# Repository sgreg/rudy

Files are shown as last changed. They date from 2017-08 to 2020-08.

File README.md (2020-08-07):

# RUDY - the Random USB Device

RUDY started out as a test and play-around device for USB development using the [Objective Development V-USB library](https://www.obdev.at/products/vusb/index.html), but also serves as standard ATmega328 development board.

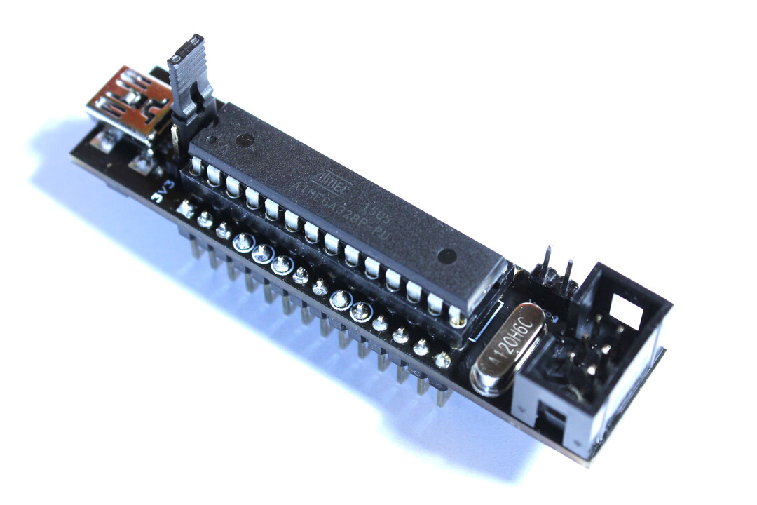
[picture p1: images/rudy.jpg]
RUDY


## Links
- [Official Website](https://rudy.craplab.fi/)
- [Hackaday.io Project Page](https://hackaday.io/project/174101-rudy)

## Features

- breadboard-friendly prototyping board, taking up only one additional row on each side compared to a standalone ATmega328 microcontroller
- Arduino compatible [..ish](firmware/arduino/)
- USB port wired to the ATmega328 for out-of-the-box USB functionality via the V-USB library
- own, dedicated [USB VID/PID pair](http://pid.codes/1209/B00B/) thanks to [pid.codes](http://pid.codes/)
- USB-powered with additional 3.3V voltage regulator on board to select either 5.0 or 3.3V supply voltage
- clocked by 12.0 MHz crystal to comply with V-USB and also 3.3V supply voltage
- 6-pin ISP header for programming, with additional option to power the board directly from the programmer
- power-indicating LEDs mounted under the IC, shining in a mysterious glow (oh yeah)
- DIP28 ATmega328, allowing easy replacement if it ever gets fried (no no)
- fully open source and [certified as such](https://certification.oshwa.org/fi000002.html) by the [Open Source Hardware Association (OSHWA)](https://www.oshwa.org/)

<p align="center">
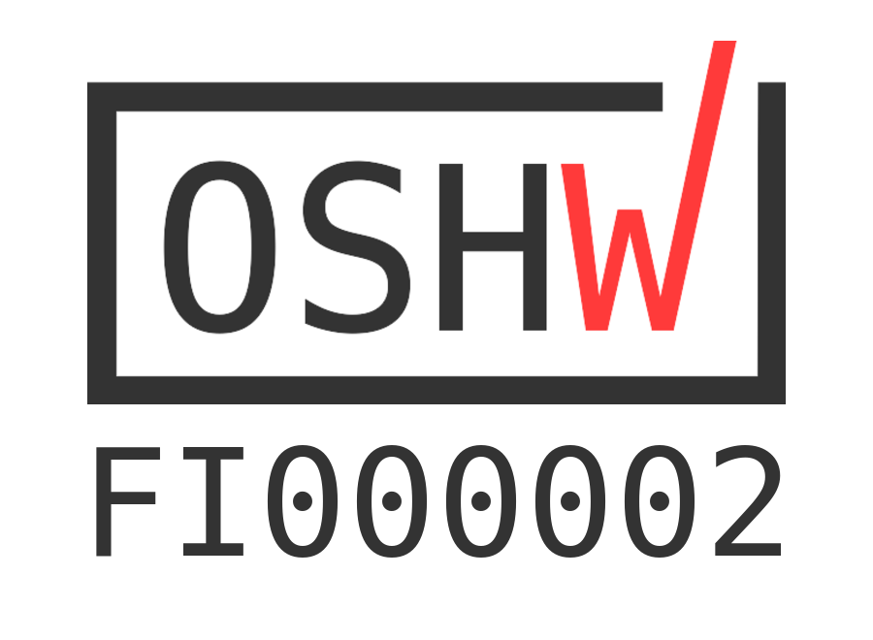
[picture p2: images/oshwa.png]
[OSHW] FI000002 Finland Number Two!

</p>

## Hardware

RUDY is primarily a hardware project, so all the design file for KiCad along with the schematic as PDF and Gerber files are found in the [`hardware/`](hardware/rudy/) directory. And if you want to go straight ahead and build your own board, [the PCB is available from OSH Park](https://oshpark.com/projects/RQf8bXd4).

As RUDY can theoretically function as an [USBasp programmer](https://www.fischl.de/usbasp/), there's also [an adapter board](hardware/usbasp-adapter) available - and is also [available from OSH Park](https://oshpark.com/projects/pueZ0qkO)

## Firmware

Again, RUDY is primarily a development board, and as such is there for _your_ firmware. But well, everything and everyone has to start somewhere, so the [`firmware/`](firmware/) directory has a (still-to-grow) collection of example projects, both using the V-USB library and using RUDY as regular, ATmega328 microcontroller board.

## License
RUDY is fully open source. All hardware files are released under the [CERN Open Hardware License v1.2](https://ohwr.org/project/licenses/wikis/cern-ohl-v1.2), all example source code is released under the [MIT License](https://choosealicense.com/licenses/mit/), and all documentation within this git repository is provided under the terms of a [Creative Commons Attribution 4.0 International (CC BY 4.0) license](https://creativecommons.org/licenses/by/4.0/).

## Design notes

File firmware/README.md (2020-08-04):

# RUDY - Firmware Examples

This is a collection of firmware examples to play around and explore RUDY with.

As RUDY is a simple ATmega328 development board, there's nothing too magical in this code collection here and will also work with any other ATmega328 board - which is kinda the point of RUDY as a rapid prototyping board. However, the examples are laid out specifically for RUDY and its hardware arrangements (like clock speed and V-USB pin configuration), so you might have to adjust a few bits if you're planning to use them on different hardware.

RUDY, being _the Random USB Device_, was initially built for use the [V-USB library](https://www.obdev.at/products/vusb/index.html), but using the library itself is of course fully optional. As V-USB adds certain complexity to the build system and code itself, The examples are split up in different folders, so focus can be put on either using RUDY as a regular ATmega328 device, and using it specifically as a USB device.

- [`v-usb/`](v-usb/) contains example to use RUDY as USB device, with main focus on the USB part itself
- [`bare-metal/`](bare-metal/) contains examples to use RUDY as a regular ATmega328 device
- [`arduino/`](arduino/) contains examples to use RUDY within the Arduino ecosystem

More information on the specifics of all that can be found inside those directories.

Note that Arduino support is more a lucky side effect of using the ATmega328 here, and not what RUDY is really aiming at. But since it's possible, I figured: why not. However, the main instructions here are for using RUDY as bare metal / bare metal + V-USB device, so if you're planning on using it in the Arduino ecosystem, you can probably skip most of the instructions here.

## Table of Contents
  * [Requirements](#requirements)
    * [Installing via provided script](#installing-via-provided-script)
    * [Installing manually](#installing-manually)
  * [Building the Examples](#building-the-examples)
  * [Powering RUDY](#powering-rudy)
    * [Powering RUDY via USB port](#powering-rudy-via-usb-port)
    * [Powering RUDY via the programmer](#powering-rudy-via-the-programmer)
  * [Flashing the Firmware](#flashing-the-firmware)
    * [Setting up the programmer](#setting-up-the-programmer)
  * [Running the Examples](#running-the-examples)
  * [Miscellaneous](#miscellaneous)
    * [Other Makefile targets](#other-makefile-targets)
    * [Troubleshooting](#troubleshooting)

## Requirements

While the focus of the examples differs, and their build environment is set up slightly different, the underlying tools to actually compile the source code and flash the resulting firmware onto the device are the same. Both use [GCC](https://gcc.gnu.org/wiki/avr-gcc) and [AVRDUDE](https://www.nongnu.org/avrdude/) wrapped into a `Makefile` to accomplish this, so you will need those tools and their dependencies installed on your computer in order to get started.

### Installing via provided script

To make sure you have everything you need installed, the [`check-system.sh`](check-system.sh) script is provided. It will check if all required executables are present on the system, and if so, compile a little dummy AVR C file and see if that succeeds. If all goes well, it means you're ready to get going with the examples, otherwise it will tell you what packages you're most likely missing.

If you're using a Debian based distribution (like Debian itself, Ubuntu or its variants, Linux Mint, or Raspbian) or a Red Hat based distribution (like Red Hat, Fedora, or CentOS), the script will even offer to install the missing packages right away. It will ask first though, so nothing is going to just happen automatically.

### Installing manually

To install all required packages depends on the Linux distribution you are using.

#### Debian / Ubuntu / Linux Mint / Raspbian / ...
```
sudo apt install make gcc-avr avr-libc binutils-avr avrdude
```
If `apt` doesn't exist, try `apt-get`.

#### Red Hat / Fedora / CentOS
```
sudo dnf install make avr-gcc avr-libc avr-binutils avrdude
```

The main difference between Debian and Red Hat based systems is the tool / architecture order of the package names, like `gcc-avr` vs `avr-gcc` as package name for GCC.

#### Other Linux distributions / operating systems

Other Linux distributions will most likely have packages with equal or somewhat similar names as the ones above. Arch for example has the same name as Red Hat.

In case of macOS, it seems to be possible to install the same toolchain via `brew`, although package names might slightly differ.

As for Windows, I'm afraid you're on your own, and I'm not sure will this even work at all under Windows as I don't have the means to test and verify this myself. WSL might help, Cygwin might be an alternative. Sorry.

(Comments and contributions on improving and extending this are very welcome!)

## Building the Examples

Unless stated otherwise, the build environment will do all the heavy lifting, and each example can be compiled by a simple call to `make` from within their dedicated directory.

For example, to compile the [V-USB Hello USB example](v-usb/01_hello-usb/), enter its directory and simply run `make`:
```
[firmware/]$ cd v-usb/01_hello_usb/
[firmware/v-usb/01_hello_usb/]$ make
avr-gcc ...
...
avr-objcopy -O ihex -R .eeprom rudy_hello-usb.elf rudy_hello-usb.hex
   text	   data	    bss	    dec	    hex	filename
   1470	      2	     43	   1515	    5eb	rudy_hello-usb.elf
[firmware/v-usb/01_hello_usb/]$
```

That's it.

## Powering RUDY

As RUDY can be powered from both USB and the programmer itself, make sure the power arrangements are set up properly. The power itself is set via a jumper, and to avoid any misconfigurations, it's best to only ever keep one single jumper around.

**Note:** the pictures below show two different devices with different LED setup each - the LEDs do not change colors depending on the supply voltage option!

### Powering RUDY via USB port

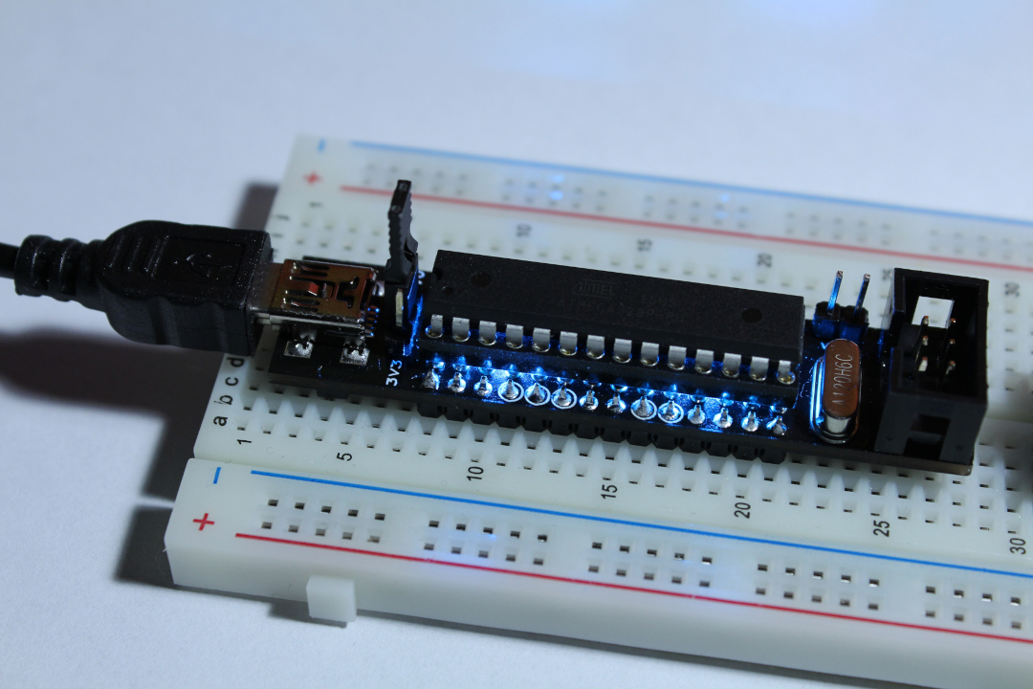
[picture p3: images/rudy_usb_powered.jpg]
RUDY powered via USB port


If RUDY is powered via USB, the jumper will be either on the 3.3V or 5.0V selector. RUDY can remain powered that way during flashing, so simply connect the ISP cable and leave the USB connected as well.

### Powering RUDY via the programmer

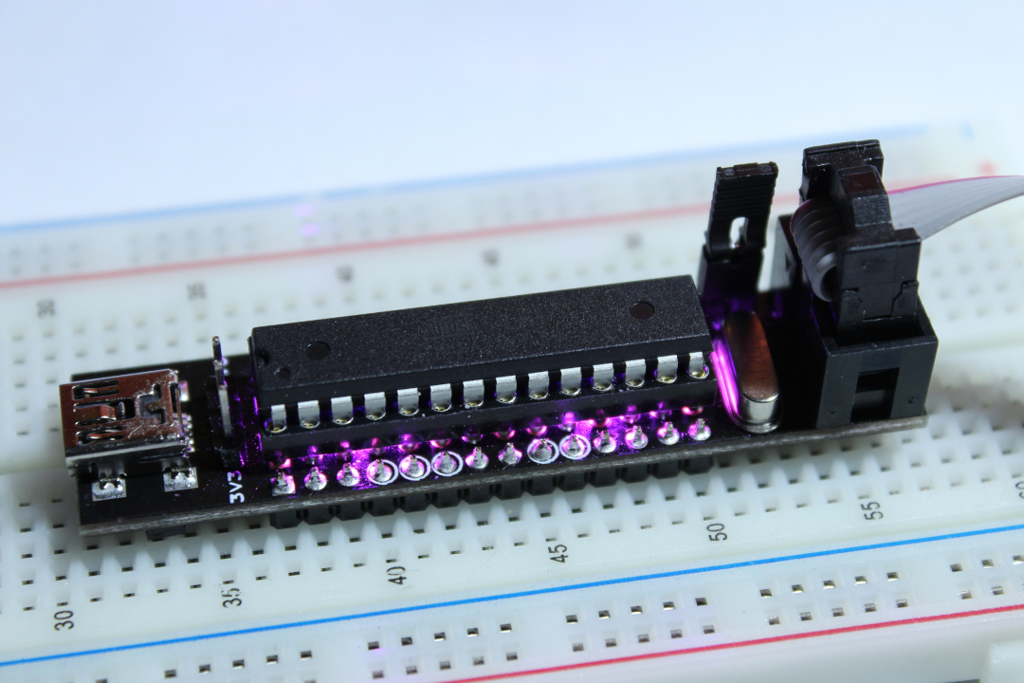
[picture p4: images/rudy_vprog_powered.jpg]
RUDY powered via programmer


Alternatively, move the jumper from the USB power selector to the pins next to the ISP port itself, where it says "Vprog". In this case, the programmer will provide the power directly to RUDY. Note that you can still use USB functionality in this setup, you just need to keep the programmer powered up so RUDY gets the power as well.

## Flashing the Firmware

As with compiling the firmware, flashing it to RUDY is also handled by the build system.

To flash the compiled firmware, connect the programmer to RUDY's 6-pin ISP port and run
```
make program
```
from within the example's directory (same place you ran `make` to compile it).

### Setting up the programmer
The build system itself is by default set up to use the [USBasp programmer](https://www.fischl.de/usbasp/), as it is a cheap, open source programmer that does the job very well. Plus, [RUDY can be programmed to act as USBasp itself](v-usb/06_usbasp/).

If you're using a different programmer, adjust the command line settings in the [`programmer.mk`](programmer.mk) file within this directory.

The default content will look like this:
```
AVRDUDE_PROGRAMMER = -c usbasp
```
and will be passed as-is as command line parameter to AVRDUDE itself.

For example, to use [Adafruit's USBtinyISP](https://learn.adafruit.com/usbtinyisp), adjust the file to:
```
AVRDUDE_PROGRAMMER = -c usbtiny
```

If you use a programmer that requires additional command line parameters, for example the port or baudrate, just add it along with the programmer itself in the `programmer.mk` file:
```
AVRDUDE_PROGRAMMER = -c avrispmkII -P usb
```

## Running the Examples

Each example acts of course differently, so please refer to each example's own documentation to see what to expect and how to use it.

## Miscellaneous

### Other Makefile targets

In addition to compiling and flashing, `make` supports a few additional targets:

- `clean` removes all intermediate compiled object files (`.o` files), which can be useful to make sure the code is built from scratch (oftentimes needed if for example a header file was changed).
- `distclean` runs `clean` and in addition also removes the fully compiled executables, HEX files and map file. This essentially returns the example directory to its clean, initial content state.
- `burn-fuse` sets the ATmega328's fuses the way RUDY needs them, which mainly concerns the clock setup. If you need to replace the microcontroller, or want to change the fuses for your own purposes, this will initialize / reset them.

### Troubleshooting

**Note:** to leave every option open to the user, RUDY doesn't come equipped with any reset circuitry. The programmer will toggle the reset line during programming, and in some cases it may happen that the line won't be released, leaving RUDY in reset state. If flashing firmware succeeded but nothing seems to happen, remove the programmer from the ISP port and re-connect RUDY via USB (make sure the voltage selection jumper is set to either 3.3V or 5.0V then).

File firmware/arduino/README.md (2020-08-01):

# RUDY - Arduino Examples

Some very brief list of examples to use RUDY within the Arduino ecosytem.

Being a generic ATmega328 development board, RUDY naturally supports to run Arduino code as it doesn't differ much from an Arduino Uno from the compiler's point of view. The main difference, apart from not being an actual Arduino board, is a lower clock frequency (12MHz instead of 16MHz), which will affect anything that uses timers and other internal clocks (delays, UART, SPI, hardware timers, etc). To make things easier, [RUDY can be supported as 3rd part board package](https://github.com/sgreg/craplab-arduino).

Keep in mind that Arduino support is more of a side effect than the primary goal, and RUDY has no Arduino bootloader installed, so an external programmer is required and the sketch needs to be uploaded via the "Upload Using Programmer" option.

## List of Examples

- [`01_blinky`](01_blinky/) the classic blinking LED Hello World example (requires external LED)

## Limitations

### No Bootloader
As mentioned, RUDY has no Arduino bootloader installed, nor USB set up in a way that adding it could be easily achieved. It's probaby still possible - somewhat, maybe? - but there are no intentions to make that happen at this point. So in order to upload a sketch, you'll need an external programmer that's set up accordingly in the Arduino, and the "Upload Using Programmer" option has to be chosen instead of the normal "Upload" one.

### No Controllable On-Board LED
While RUDY does have LEDs, they are meant as power indicator, and are not connected to any of the ATmega328's pins<sup>[1]</sup>. So in order to run the [Blinky example](01_blinky/) (or any other simple LED blinking code), an external LED is needed.

<sup>[1]</sup> I thought about that option but decided against it, as the LEDs' primary purpose is to indicate that the board is actually powered on (and by that to avoid chasing ghosts in the code in case the jumpers were simply mixed up)

### Some Pins Shouldn't Be Used

Since RUDY has the V-USB circuitry wired to the ATmega328 - after all, USB development was the primary motivation for this board - those pins shouldn't be used for any other purpose, even if V-USB itself isn't used.

The pins in question have a circle placed around them on the board, which are:

| ATmega pin | Arduino pin | Usage |
| :---: | :---: | ---- |
| 4 | 2 | USB D+ |
| 5 | 3 | USB D- |
| 6 | 4 | USB Reset |
| 9 | - | external crystal oscillator |
| 10 | - | external crystal oscillator |

## Pinout

Again, RUDY uses the same microncontroller as the Arduino Uno, so the pinout from Arduino's point of view is identical

```
                                   _______
                              .---|       |---.
                              | [ ]       [ ] |
                              |   |       |   |
                              |   |       |   |
                              | [ ]_|||||_[ ] |
                              |               |
                              |3V3 o  o  o 5V0|
                              |   ___   ___   |
                   Reset ---- |o-| 1 \_/ 28|-o| ---- A5
                  (RX) 0 ---- |o-| 2     27|-o| ---- A4
                  (TX) 1 ---- |o-| 3     26|-o| ---- A3
                       x ---- |o-| 4     25|-o| ---- A2
                       x ---- |o-| 5     24|-o| ---- A1
                       x ---- |o-| 6     23|-o| ---- A0
                     VCC ---- |o-| 7     22|-o| ---- GND
                     GND ---- |o-| 8     21|-o| ---- AREF
                 Crystal ---- |o-| 9     20|-o| ---- AVCC
                 Crystal ---- |o-|10     19|-o| ---- 13
                 (PWM) 5 ---- |o-|11     18|-o| ---- 12
                 (PWM) 6 ---- |o-|12     17|-o| ---- 11 (PWM)
                       7 ---- |o-|13     16|-o| ---- 10 (PWM)
                       8 ---- |o-|14     15|-o| ----  9 (PWM)
                              |  '---------'  |
                              | _________     |
                              |/         \  o |
                              |\_________/  o |
                              | ____     ____ |
                              ||    '---'    ||
                              ||   o  o  o   ||
                              ||   o  o  o   ||
                              ||_____________||
                              '---------------'
```

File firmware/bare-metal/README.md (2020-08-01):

# RUDY - Bare Metal Examples

This is a (very small) collection of examples to use RUDY as a regular, ATmega328 device.

- [`01_blinky`](01_blinky/) the classic blinking LED Hello World example

To compile and flash the examples, please see the general instructions in [the parent directory's README](../). For additional information on the examples themselves, check their individual directories.

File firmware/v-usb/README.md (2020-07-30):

# RUDY - V-USB Examples

This is a collection of examples that will turn RUDY into a USB device using the [V-USB library](https://www.obdev.at/products/vusb/index.html).

## List of Examples

- [`01_hello-usb`](01_hello-usb/) a dummy USB device that will simply just show up as such in the system, but doesn't have any actual functionality
- [`02_usb-led`](02_usb-led/) controlling an LED via USB to turn it on, off, or to a specified PWM value, including Python script to communicate with it
- [`03_caesar`](03_caesar/) sending messages from a Python script to the USB device and receiving them back "encrypted" via [Caesar Cipher](https://en.wikipedia.org/wiki/Caesar_cipher)
- [`04_midi`](04_midi/) a USB MIDI device that uses analog-to-ditigal conversion to turn sensor values into MIDI notes
- [`05_vusb-hid-mouse`](05_vusb-hid-mouse/) the [V-USB HID Mouse example](https://github.com/obdev/v-usb/tree/master/examples/hid-mouse) that acts as a common mouse that moves in circles, adjusted for RUDY
- [`06_usbasp`](06_usbasp/) turning RUDY into the [USBasp AVR programmer](https://www.fischl.de/usbasp/)

For additional information on the examples themselves, check their individual directories.

## Compiling and Flashing

To compile and flash the examples, please see the general instructions in [the parent directory's README](../). As the build system is designed to keep it as straightforward and consistent as possible between the different examples, they all share the same [common build environment](common/), and therefore building and flashing will be the same for all of them.

If the examples don't have any specific build instructions themselves, it means that there's nothing different about them and the common compiling and flashing instructions apply.

## Running Control Application

Some of the examples come with a host-side control application in form of a Python script, for example the [USB LED Example](02_usb-led). The script themselves require Python3 and the [PyUSB module](https://github.com/pyusb/pyusb) installed. PyUSB can be usually installed via your Linux distribution's package manager, or via `pip install pyusb`.

In order to run the script, the user must have read/write access to the USB device itself, which usually won't be the case out of the box, or else the script will fail to run with something like `ValueError: The device has no langid`. There are two ways to get this working:

1. run the scripts as root via `sudo`
2. add a `udev` rule for the device

While the first option surely is the easy option to make it work, it's recommended to go for the second option.

### Add udev Rule

To add a `udev` rule, a rule file needs to be located in `/etc/udev/rules.d/` with the following content:
```
SUBSYSTEM=="usb", ATTRS{idVendor}=="1209", ATTRS{idProduct}=="b00b", MODE="0666"
```

The rule makes sure that every USB device with a VID/PID combination of 0x1209/0xb00b (i.e. the [official id pair](http://pid.codes/1209/B00B/) for RUDY) will have its permission set to `0666`, i.e. read/write permission for everyone.

The file name itself is usually in a form of `xx-something.rules`, with `xx` being a number to enforce the run order (as the rules are processed in alphabetical order). For RUDY, the file could be called `50-rudy.rules`, and you either use and editor to create the file (needs `sudo` to write in that directory), or `echo` and `tee` it there:
```
$ echo 'SUBSYSTEM=="usb", ATTRS{idVendor}=="1209", ATTRS{idProduct}=="b00b", MODE="0666"' |sudo tee /etc/udev/rules.d/50-rudy.rules
```

Once the file is added to `/etc/udev/rules.d`, reload the rules.
```
$ sudo udevadm control --reload-rules
$ sudo udevadm trigger
```

You should now be able to run the host-side scripts successfully.

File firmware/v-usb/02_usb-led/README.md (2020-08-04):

# RUDY - V-USB Example 02: USB LED

Control an LED via USB to turn it on, off, or to a given PWM duty cycle value.

This example is split into a [`device/`](device/) directory that has the firmware for RUDY, and a [`host/`](host/) directory that has the host-side control software in form of a Python script.

## Set it up

The device is set up the same way as the [bare metal Blinky example](../../bare-metal/01_blinky/), with the LED expected at GPIO port PD5 / pin 11 of the microcontroller. It's a good idea to add a [current-limiting resistor](https://www.sparkfun.com/tutorials/219) in series with the LED to lower the risk of accidentally destroying it. The value of that resistor depends on the LED itself, but a good starting value would be for example 120 &Omega;.

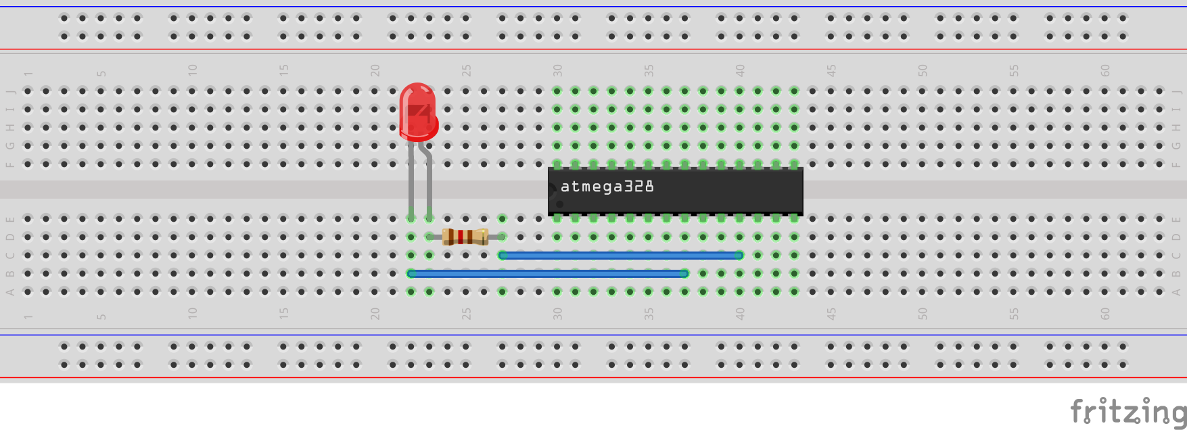
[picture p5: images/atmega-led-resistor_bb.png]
Breadboard arrangements for USB LED example


## Build and flash it

The general instruction in the [parent directory's README](../) apply here, except the firmware itself is found in the [`device/`](device/) directory, so the `make` commands need to be run from within that directory instead of the example's main directory.

## Use it

If everything went well and the hardware is set up correctly, once the device is plugged in, the LED should turn on in a semi-bright manner and the following information should be visible in the syslog or `dmesg`:

```
[106972.432085] usb 2-3.3: new low-speed USB device number 36 using xhci_hcd
[106972.529252] usb 2-3.3: New USB device found, idVendor=1209, idProduct=b00b, bcdDevice= 1.00
[106972.529256] usb 2-3.3: New USB device strings: Mfr=1, Product=2, SerialNumber=3
[106972.529259] usb 2-3.3: Product: RUDY
[106972.529261] usb 2-3.3: Manufacturer: CrapLab
[106972.529263] usb 2-3.3: SerialNumber: LED Example
```

If the LED doesn't light up, double-check that you are using the expected pin (by default port PD5 on pin 11).

### Python control script

The Python control script requires Python3 and the [PyUSB module](https://github.com/pyusb/pyusb) installed. PyUSB can be usually installed via your Linux distribution's package manager, or via `pip install pyusb`.

If you have both available, you should be able to run the [`ledcontrol.py`](host/ledcontrol.py) script located in the [`host`](host/) directory.

```
[02_usb-led/]$ cd host/
[02_usb-led/host/]$ ./ledcontrol.py 
Welcome to LED Example

Available commands:
on              turn LED on
off             turn LED off
pwm             read the current PWM value
pwm <value>     set LED to given PWM value
                value can be either decimal [0..255] or hexadecimal [0x00..0xff]
q | quit        quit

> 
```

Follow the instructions of the available commands, and you should be able to turn the led fully `on`, `off`, or anything in between with the given `pwm` value.

If the script says "`Error: No device found`", make sure you have flashed RUDY with the correct example firmware, the device is [powered correctly](../../#powering-rudy), and it shows up in the syslog or `lsusb` output.

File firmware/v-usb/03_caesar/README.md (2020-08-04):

# RUDY - V-USB Example 03: Caesar Cipher

A USB implementation of the [Caesar Cipher](https://en.wikipedia.org/wiki/Caesar_cipher), which "encrypts" a message by shifting letters a certain amount of positions. A message is sent to the device and stored there, and can later be requested back in "encrypted" form. Note that the quotes are purposely used here, while technically it could be considered as an encryption mechanism, the Caesar Cipher isn't really of much use for actual encryption. It's good for a USB communication / data transfer example though.

This example is split into a [`device/`](device/) directory that has the firmware for RUDY, and a [`host/`](host/) directory that has the host-side control software in form of a Python script.

## Set it up

No other components are used in this example.

## Build and flash it

The general instruction in the [parent directory's README](../) apply here, except the firmware itself is found in the [`device/`](device/) directory, so the `make` commands need to be run from within that directory instead of the example's main directory.

## Use it

If everything went well and the hardware is set up correctly, once the device is plugged in, the following information should be visible in the syslog or `dmesg`:

```
[252898.876553] usb 2-3.4: new low-speed USB device number 65 using xhci_hcd
[252899.185018] usb 2-3.4: New USB device found, idVendor=1209, idProduct=b00b, bcdDevice= 1.00
[252899.185022] usb 2-3.4: New USB device strings: Mfr=1, Product=2, SerialNumber=3
[252899.185025] usb 2-3.4: Product: RUDY
[252899.185027] usb 2-3.4: Manufacturer: CrapLab
[252899.185030] usb 2-3.4: SerialNumber: Caesar Cipher
```

### Python control script

The Python control script requires Python3 and the [PyUSB module](https://github.com/pyusb/pyusb) installed. PyUSB can be usually installed via your Linux distribution's package manager, or via `pip install pyusb`.

If you have both available, you should be able to run the [`caesarcontrol.py`](host/caesarcontrol.py) script located in the [`host`](host/) directory.

```
[03_caesar/]$ cd host/
[03_caesar/host/]$ ./caesarcontrol.py 
Welcome to the Caesar Cipher Control Application

Available commands:
init <message>  Initialize the device with the given message.
                This sends the message to the device and stores it there.
                Later calls to "cipher <shift"> command will be based on
                this message, so make sure this is called at least once.

cipher <shift>  Retrieve the message previously sent via "init <message>"
                command shifted by the given amount. The shift value can
                be also negative to shift in the other direction.

q | quit        Quit the control application.

Example usage:
> init hello RUDY
Device initialized
> cipher 10
rovvy BENI

>
```

If the script says "`Error: No device found`", make sure you have flashed RUDY with the correct example firmware, the device is [powered correctly](../../#powering-rudy), and it shows up in the syslog or `lsusb` output.

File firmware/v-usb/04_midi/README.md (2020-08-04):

# RUDY - V-USB Example 04: USB MIDI Device

Turn RUDY into a USB MIDI device, using analog-to-digital conversion as playback source.

Periodically reads sensor values from the ATmega's ADC and converts the read values into MIDI notes. The MIDI part itself is taken directly from [4chord MIDI](https://github.com/sgreg/4chord-midi) and its own [USB setup](https://github.com/sgreg/4chord-midi/blob/master/firmware/usb.c), as it has proven well functioning. The ADC handling is rather basic but good enough for this purpose - for more serious analog-to-digital conversion applications, it's recommended to take a look at the [_ADC of megaAVR in Single-Ended Mode_ Application Note](http://ww1.microchip.com/downloads/en/AppNotes/AN2538-ADC-of-megaAVR-in-SingleEnded-Mode-00002538A.pdf) (AN2538 / AVR126).

## Some details

The MIDI standard provides us with 127 possibles notes to play, but in practice, the lower and higher end of that spectrum wasn't all that pleasant to listen to. To still make use of the ADC's full range, the MIDI notes will be limited to a more useful range in the center of the spectrum - namely from note 28 (E1) to note 91 (G6). As the Atmega328 uses a 10-bit ADC, we simply take only the top 6 bit, which gives us 64 values that aren't too sensitive to small changes in the sensor readings, and add an offset of 28 to them.

For example:
```
                  from 0x2c0 == 704
                    to 0x2cf == 719
                /                   \
Raw ADC value:  1 0  1 1 0 0  x x x x
                \          /
Top 6 bits:      0x2c == 44
Offset:                + 28
                       -----
MIDI note:               72 == C4
```

Any ADC value between 704 and 719 (inclusive) is going to end up as a C4 note. Due to this range, tiny variations in the reading won't have any too big impact on the playback, therefore a simple ADC hardware setup will do here.

## Set it up

The device is set up to expect a sensor connected to analog channel 0, i.e. `ADC0` / `PC0` on pin 23. An example sensor could be a simple light-dependent resistor (LDR), also known as a [photoresistor](https://en.wikipedia.org/wiki/Photoresistor) or simply a light sensor, but practically any [voltage divider](https://en.wikipedia.org/wiki/Voltage_divider) with a variable resistor will work - for example a [thermistor](https://en.wikipedia.org/wiki/Thermistor) as temperature sensor, or even just a regular potentiometer.

Alternatively, a sensor that directly outputs its voltage - like an ADXL335 accelerometer or LM35 temperature sensor - could be connected straight to the ADC pin without the need of a voltage divider.

But here's what a set up with a variable resistor and voltage divider could look like:

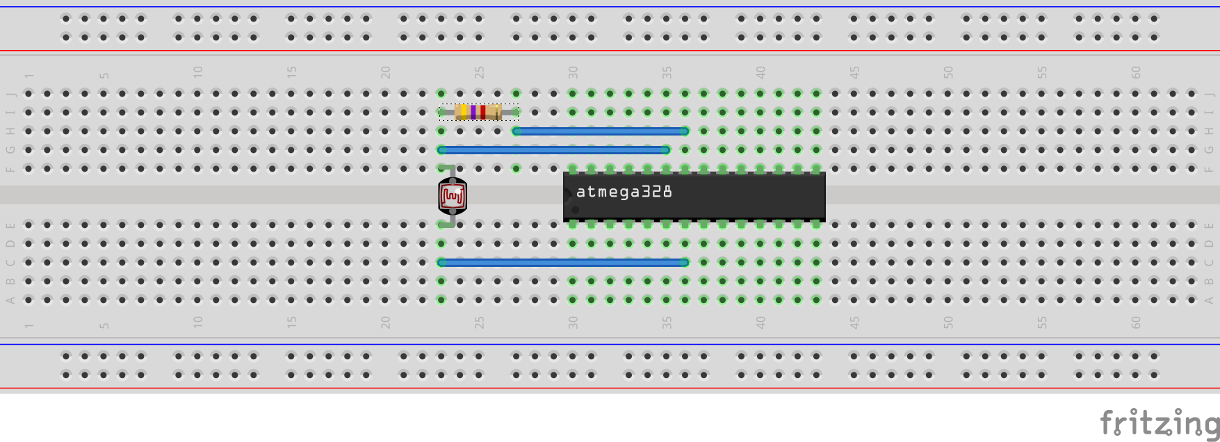
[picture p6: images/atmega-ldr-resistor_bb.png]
Breadboard arrangements for USB MIDI example


In this case, the brighter the light is shining onto the photoresistor, the lower its resistance will be, and therefore the higher the voltage the ADC will read. A higher voltage results in a higher value received from the ADC which determines the MIDI note, so in other words: the brighter the light, the higher the note it will send - and vice versa.

## Use it

When plugging in, the following information should be visible in the syslog or `dmesg`:

```
[ 6052.830880] usb 2-3.4: new low-speed USB device number 23 using xhci_hcd
[ 6053.373418] usb 2-3.4: New USB device found, idVendor=1209, idProduct=b00b, bcdDevice= 1.00
[ 6053.373422] usb 2-3.4: New USB device strings: Mfr=1, Product=2, SerialNumber=0
[ 6053.373424] usb 2-3.4: Product: RUDY
[ 6053.373426] usb 2-3.4: Manufacturer: CrapLab
[ 6059.558949] usb 2-3.4: USB disconnect, device number 23
```

Note that even though [`usbconfig-rudy.h`](usbconfig-rudy.h) sets a serial number, it won't be in use here. `lsusb` won't show it either, it will however show that is indeed an `Audio` class with `MIDI Streaming` as subclass:

```
$ lsusb |grep CrapLab
Bus 002 Device 023: ID 1209:b00b Generic CrapLab Random Device

$ lsusb -vs 002:023

Bus 002 Device 023: ID 1209:b00b Generic CrapLab Random Device
Device Descriptor:
...
  idVendor           0x1209 Generic
  idProduct          0xb00b CrapLab Random Device
  bcdDevice            1.00
  iManufacturer           1 CrapLab
  iProduct                2 RUDY
  iSerial                 0
...
    Interface Descriptor:
...
      bInterfaceClass         1 Audio
      bInterfaceSubClass      3 MIDI Streaming
...
```

### Use it as MIDI device

To verify that it's recognized as an actual MIDI device, we can for example use `aconnect` (which is part of [alsa-utils](https://github.com/alsa-project/alsa-utils) that should be available in your Linux distro's package manger), where it should show up as input device:
```
$ aconnect -i
...
client 24: 'RUDY' [type=kernel,card=2]
    0 'RUDY MIDI 1     '
```

We can connect the device for example to FluidSynth (I wrote some detailed instructions on that for [the 4chord MIDI project](https://github.com/sgreg/4chord-midi#simple-playback-with-fluidsynth)), or use `aseqdump`, which is also part of the alsa-utils package. To catch the events of the right device, we need to provide the device's port, which `aconnect` earlier showed - in this case, it's `client 24` and its id `0`, therefore `24:0`.
```
$ aseqdump -p 24:0
Waiting for data. Press Ctrl+C to end.
Source  Event                  Ch  Data
 24:0   Note on                 0, note 44, velocity 127
 24:0   Note off                0, note 44, velocity 127
 24:0   Note on                 0, note 43, velocity 127
 24:0   Note off                0, note 43, velocity 127
 24:0   Note on                 0, note 48, velocity 127
...
```
Your output may vary, as it reads the ADC value and your setup may be different, but the main principle should be the same.

Congrats, you can now connect it to a software synthesizer and play music with RUDY!

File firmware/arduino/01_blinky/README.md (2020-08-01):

# RUDY - Arduino Example 01: Blinky

Implements the classic hardware-equivalent of a Hello World: Blinking an LED.

## Setting it up

By default, the code expects the LED to be connected to Arduino's Digital Pin 5, located at pin 11. It is always recommended to use a [current limiting resistor](https://www.sparkfun.com/tutorials/219) in series with the LED to lower the risk of accidentally destroying it. The value of that resistor depends on the LED itself, but a good starting value would be for example 120 &Omega;.

Breadboard arrangements for USB LED example

## Running it

Open the example `.ino` file in the Arduino IDE and make sure RUDY is selected as active board ([see here](https://github.com/sgreg/craplab-arduino) to add board support for RUDY)

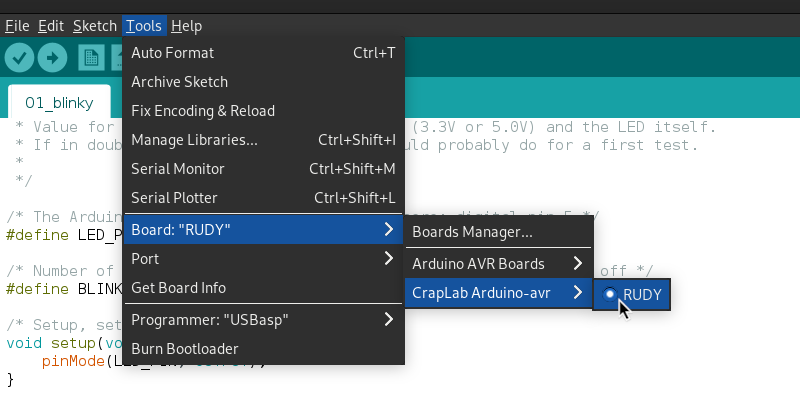
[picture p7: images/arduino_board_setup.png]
RUDY selected as current board in the Arduino IDE


Alternatively, you can select the Arduino Uno as board, but be aware that RUDY has a lower clock speed (12MHz vs 16Mhz), so the actual blink delay won't match what you declare it as.

Next, connect your external programmer to RUDY and set it up in the Arduino IDE. There are many programmers available, so best thing is to just check online how to do that with your specific one. Once that's set up, upload the sketch - but remember to use the "Upload Using Programmer" option here!

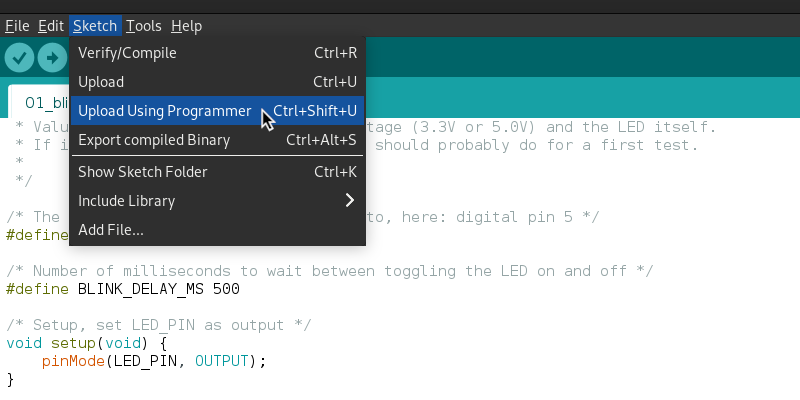
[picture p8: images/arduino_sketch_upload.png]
Upload Using Programmer selection in the Arduino IDE


Tadaa - the LED connected to Digital Pin 5 (ATmega328 pin 11) should now blink.

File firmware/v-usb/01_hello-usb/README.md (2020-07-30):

# RUDY - V-USB Example 01: Hello USB

A simple, dummy USB device that does nothing but being recognized as such.

## Set it up

This example won't use any external components, so it requires is to plug the device via USB into your computer. Make sure you have the [jumper set correctly so the device powers up](../../#powering-rudy).

Once plugged in, the following information should be visible in the syslog or `dmesg` output:

```
[39185.651461] usb 2-3.3: new low-speed USB device number 17 using xhci_hcd
[39185.746374] usb 2-3.3: New USB device found, idVendor=1209, idProduct=b00b, bcdDevice= 1.00
[39185.746379] usb 2-3.3: New USB device strings: Mfr=1, Product=2, SerialNumber=0
[39185.746383] usb 2-3.3: Product: RUDY
[39185.746385] usb 2-3.3: Manufacturer: CrapLab
[39185.746386] usb 2-3.3: SerialNumber: Hello USB

```

And `lsusb` should show us a line like this:

```
Bus 002 Device 017: ID 1209:b00b Generic CrapLab Random Device
```

Having the bus (`002`) and device number (`017`, which matches the first `USB device number 17` line in the system log), we can use `lsusb` for some additional, verbose information about that device:

```
$ lsusb -v -s 002:017

Bus 002 Device 017: ID 1209:b00b Generic CrapLab Random Device
Device Descriptor:
  bLength                18
  bDescriptorType         1
  bcdUSB               1.10
  bDeviceClass          255 Vendor Specific Class
  bDeviceSubClass         0 
  bDeviceProtocol         0 
  bMaxPacketSize0         8
  idVendor           0x1209 Generic
  idProduct          0xb00b CrapLab Random Device
  bcdDevice            1.00
  iManufacturer           1 CrapLab
  iProduct                2 RUDY
  iSerial                 3 Hello USB
  bNumConfigurations      1
  Configuration Descriptor:
...
```

There's plenty more output, but this shows the interesting parts that make it clear this is indeed the Hello USB RUDY device. Hooray!

## Using it

This serves really only as a *very* simple Hello-World-ish example, so showing up in the syslog and `lsusb` is all there is to this.

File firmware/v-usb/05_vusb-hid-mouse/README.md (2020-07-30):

# RUDY - V-USB Example 05: HID Mouse

This is the HID Mouse example taken straight from the [V-USB example](https://github.com/obdev/v-usb/tree/master/examples/hid-mouse) and adjusted to match for RUDY. All it does is act as a Mouse that moves around in circles.

The only real adjustment here is in the [`usbconfig-rudy.h`](usbconfig-rudy.h) values to match the ones set for the V-USB example. The code itself, written by Christian Starkjohann, is left as-is.

When plugged in, something along the following information should be visible in the syslog or `dmesg`:

```
186709.076775] usb 2-3.4: new low-speed USB device number 98 using xhci_hcd
[186709.171360] usb 2-3.4: New USB device found, idVendor=1209, idProduct=b00b, bcdDevice= 1.00
[186709.171366] usb 2-3.4: New USB device strings: Mfr=1, Product=2, SerialNumber=0
[186709.171369] usb 2-3.4: Product: RUDY
[186709.171372] usb 2-3.4: Manufacturer: CrapLab
[186709.184325] input: CrapLab RUDY as /devices/pci0000:00/0000:00:14.0/usb2/2-3/2-3.4/2-3.4:1.0/0003:1209:B00B.0003/input/input62
[186709.184642] hid-generic 0003:1209:B00B.0003: input,hidraw0: USB HID v1.01 Mouse [CrapLab RUDY] on usb-0000:00:14.0-3.4/input0
```

See the [V-USB repository](https://github.com/obdev/v-usb/tree/master/examples/hid-mouse) for more information.

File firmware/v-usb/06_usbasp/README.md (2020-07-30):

# RUDY - V-USB Example 06: USBasp AVR Programmer

[Thomas Fischl](https://www.fischl.de/)'s awesome [USBasp AVR programmer](https://www.fischl.de/usbasp/) adjusted for RUDY. If combined with the [USBasp adapter board](../../../hardware/usbasp-adapter/) (or a breadboard arrangement of that), RUDY can serve as actual USBasp programmer for any supported AVR device, including other RUDYs.

### Changes to original USBasp firmware

Since USBasp itself is built around V-USB, the required adjustments were rather minimal, and mostly concerned the build system and matching up the usbconfig.h file. There was however a small issue that required actual code adjustments in [`main.c`](main.c), as the original USBasp's hardware differs from RUDY. To make the changes clearer and easier reproducible, [a patch](rudy.patch) is included here.

The code here is based on the latest USBasp 2011-05-28 release (huh, it's been a while). To reproduce all the changes, download and extract the archive from the [USBasp website](https://www.fischl.de/usbasp/) and apply the patch to its `firmware/` directory:

```
[...]$ wget https://www.fischl.de/usbasp/usbasp.2011-05-28.tar.gz
[...]$ tar tzf usbasp.2011-05-28.tar.gz
[...]$ cd usbasp.2011-05-28/firmware/
[.../usbasp.2011-05-28/firmware/]$ patch < /path/to/rudy/firmware/v-usb/05-usbasp/rudy.patch
patching file main.c
patching file Makefile
patching file usbconfig.h
patching file usbconfig-rudy.h
[.../usbasp.2011-05-28/firmware/]$ 
```

In case you want to compile and flash it right away from within the USBasp code base then, you'll also need the [`common/`](../common) directory, so make sure to copy that in the USBasp root directory.
```
[.../usbasp.2011-05-28/firmware/]$ cp -a /path/to/rudy/firmware/v-usb/common/ ../
[.../usbasp.2011-05-28/firmware/]$ make
....
<this will include some warnings due to more pedantic warnings flags>
...
   text	   data	    bss	    dec	    hex	filename
   4496	      2	     72	   4570	   11da	rudy_usbasp.elf
[.../usbasp.2011-05-28/firmware/]$ 
```

## Plugging in

As tools like `avrdude` require an actual USBasp device, the usbconfig.h is adjusted to act one, so unlike the other examples, RUDY won't act as itself here, and when plugged in, syslog or `dmesg` should output something like this:

```
Jul 23 18:34:54 craptop kernel: usb 2-3.4: new low-speed USB device number 106 using xhci_hcd
Jul 23 18:34:54 craptop kernel: usb 2-3.4: New USB device found, idVendor=16c0, idProduct=05dc, bcdDevice= 1.00
Jul 23 18:34:54 craptop kernel: usb 2-3.4: New USB device strings: Mfr=1, Product=2, SerialNumber=0
Jul 23 18:34:54 craptop kernel: usb 2-3.4: Product: USBasp
Jul 23 18:34:54 craptop kernel: usb 2-3.4: Manufacturer: www.fischl.de
```

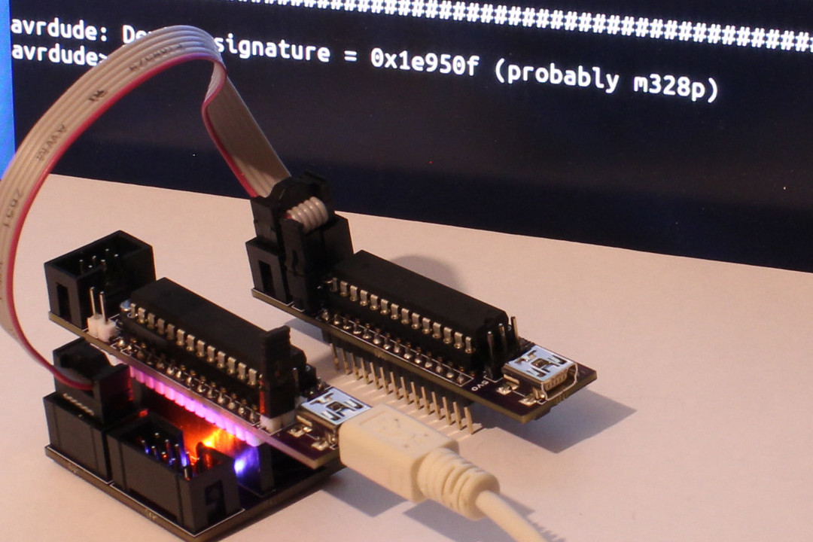
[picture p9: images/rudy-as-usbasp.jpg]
RUDY as USBasp programming another RUDY


**Note:** you might need to stick to 5.0V voltage selector for the device that acts as USBasp if you want to power another RUDY straight from it when programming.

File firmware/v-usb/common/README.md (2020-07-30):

# RUDY - Common Files for V-USB Examples

All V-USB examples have common parts for both the source code and the build environment that are collected here. This keeps the examples themselves short and focused on the part they're actually implementing, and makes extending / adding new examples easier.

- `common.mk` the main Makefile, setting up all the `make` targets, the general compiler settings as well as AVRDUDE flags, and is included in each project-specific `Makefile`.
- `usbdrv/` contains the [V-USB library](https://www.obdev.at/products/vusb/index.html) source code as-is, and is based on the vusb-20121206 release
- `usbconfig.h` the main V-USB configuration file, set up to correspond with RUDY's pin configuration, and defining most other values as `RUDY_` prefixed constants that each example source can define as required
- `usbconfig-rudy.h` a default implementation of those `RUDY_` prefixed, project-specific values in case a project itself doesn't define its own header file for that. This primarily serves as a sample template and causes a warning if it's included, as it's recommended that an example will have its own version of this.

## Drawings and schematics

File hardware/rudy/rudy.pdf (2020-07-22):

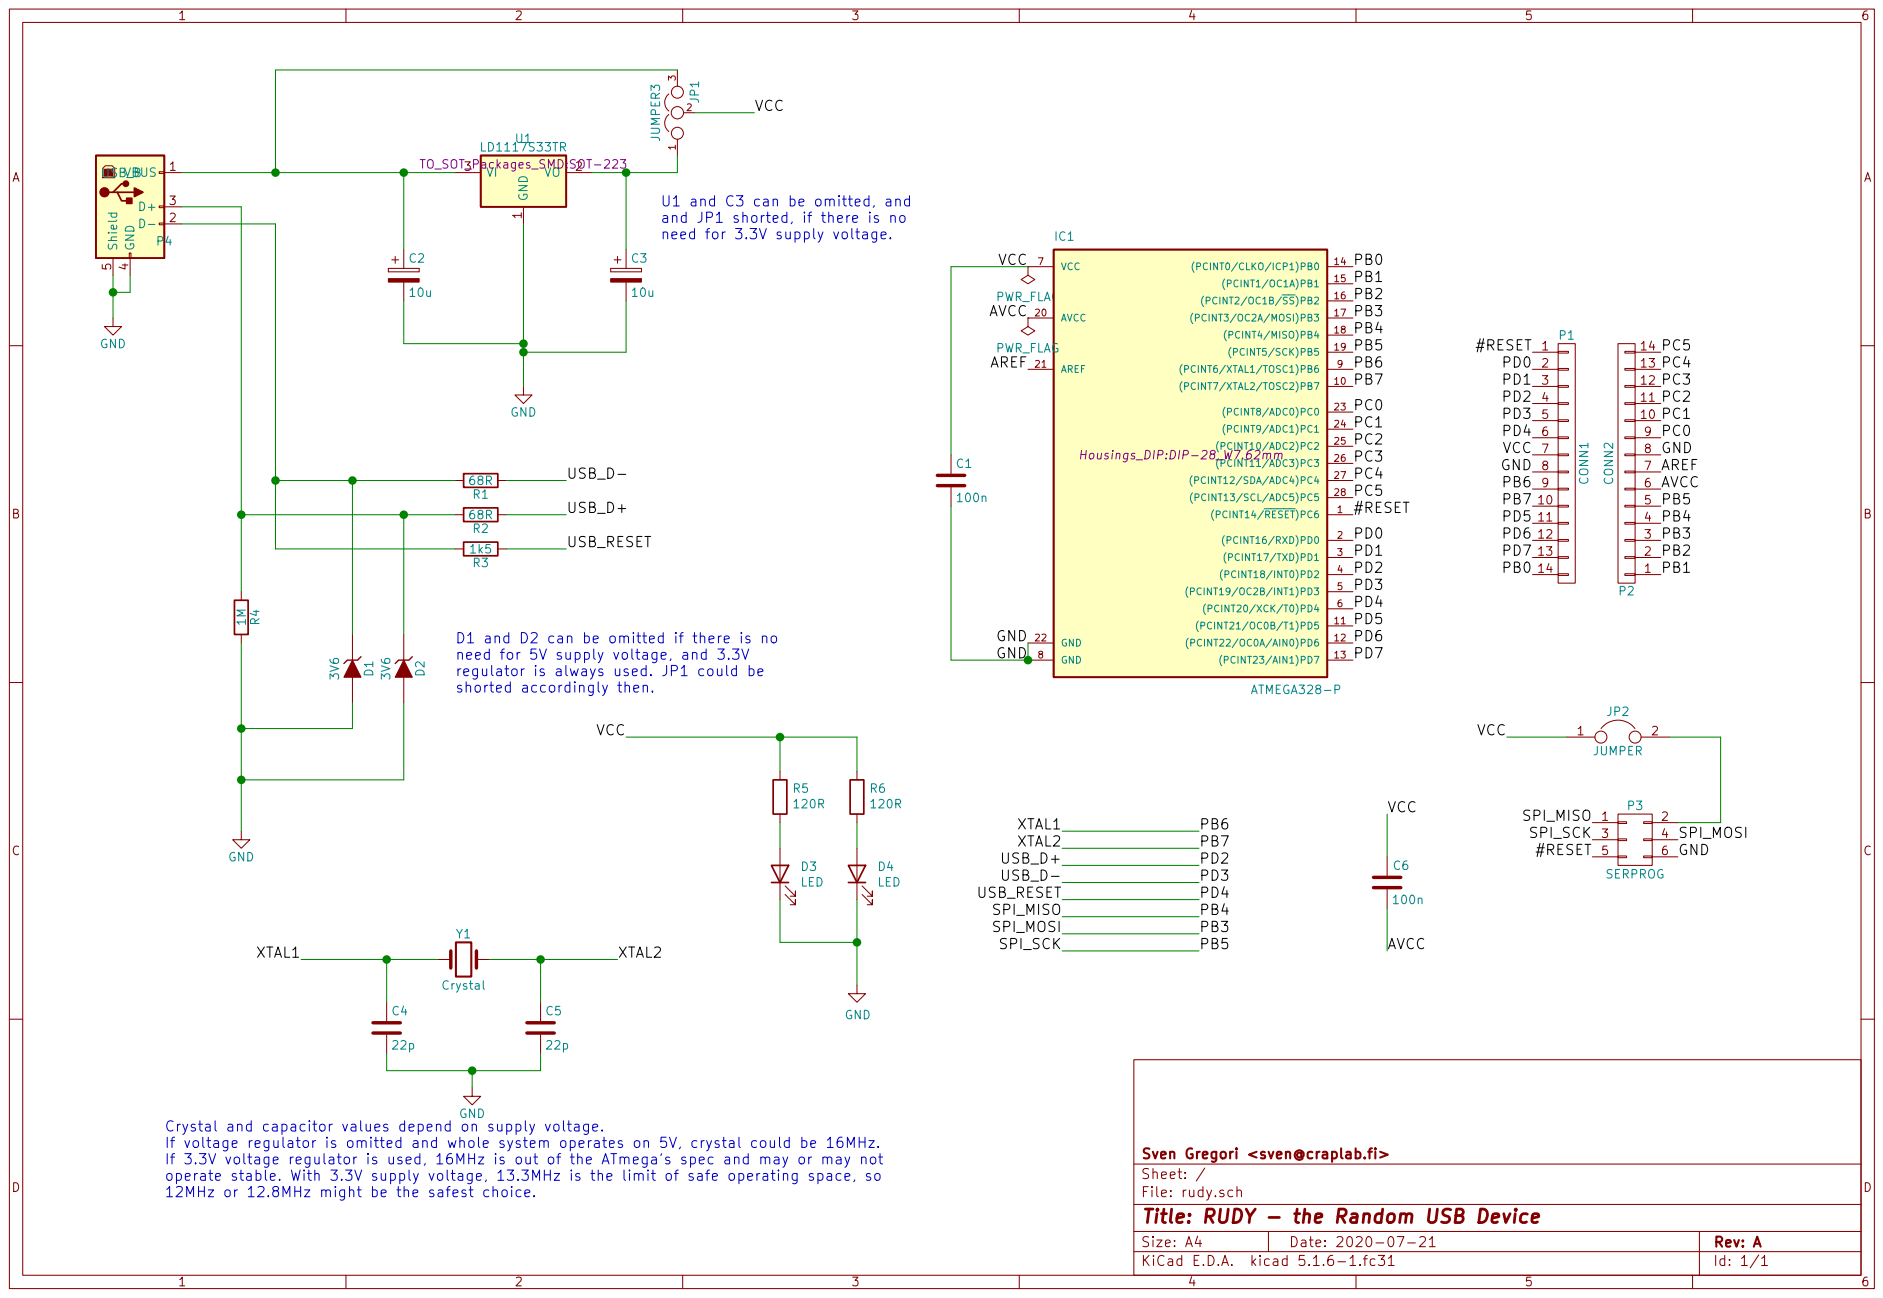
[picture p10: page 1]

U1 and C3 can be omitted, and
and JP1 shorted, if there is no
need for 3.3V supply voltage.

12MHz or 12.8MHz might be the safest choice.D1 and D2 can be omitted if there is no

need for 5V supply voltage, and 3.3V
regulator is always used. JP1 could be
shorted accordingly then.

File: rudy.sch Sheet: / Sven Gregori <sven@craplab.fi> C5

Crystal and capacitor values depend on supply voltage.
If voltage regulator is omitted and whole system operates on 5V, crystal could be 16MHz.
If 3.3V voltage regulator is used, 16MHz is out of the ATmega's spec and may or may not
operate stable. With 3.3V supply voltage, 13.3MHz is the limit of safe operating space, so

Id: 1/1 Title: RUDY - the Random USB Device

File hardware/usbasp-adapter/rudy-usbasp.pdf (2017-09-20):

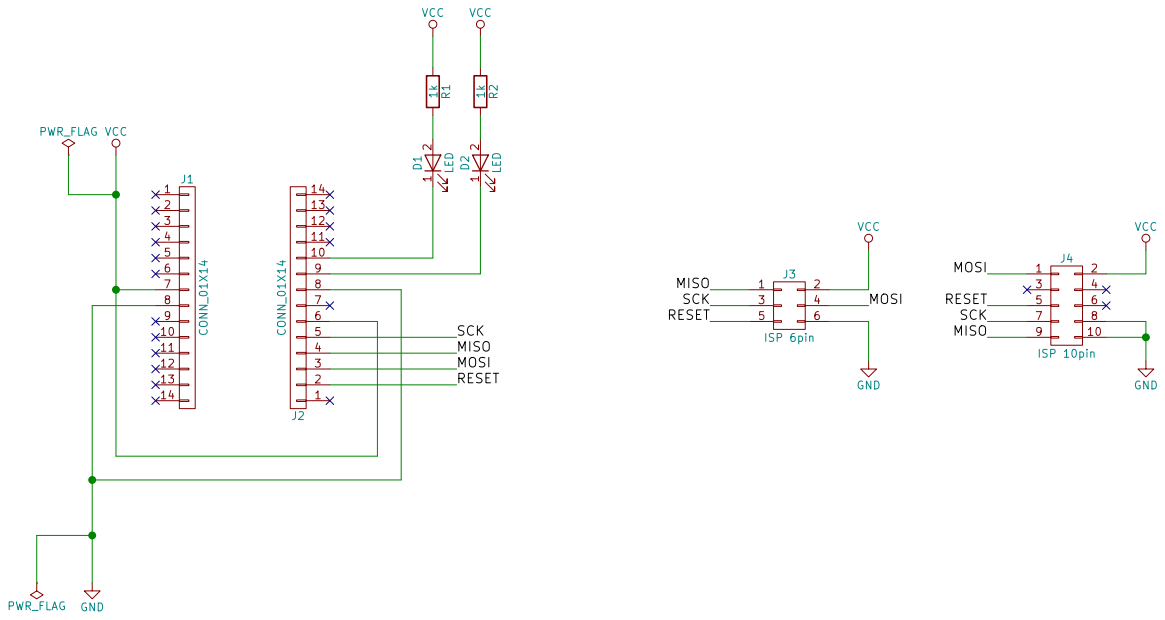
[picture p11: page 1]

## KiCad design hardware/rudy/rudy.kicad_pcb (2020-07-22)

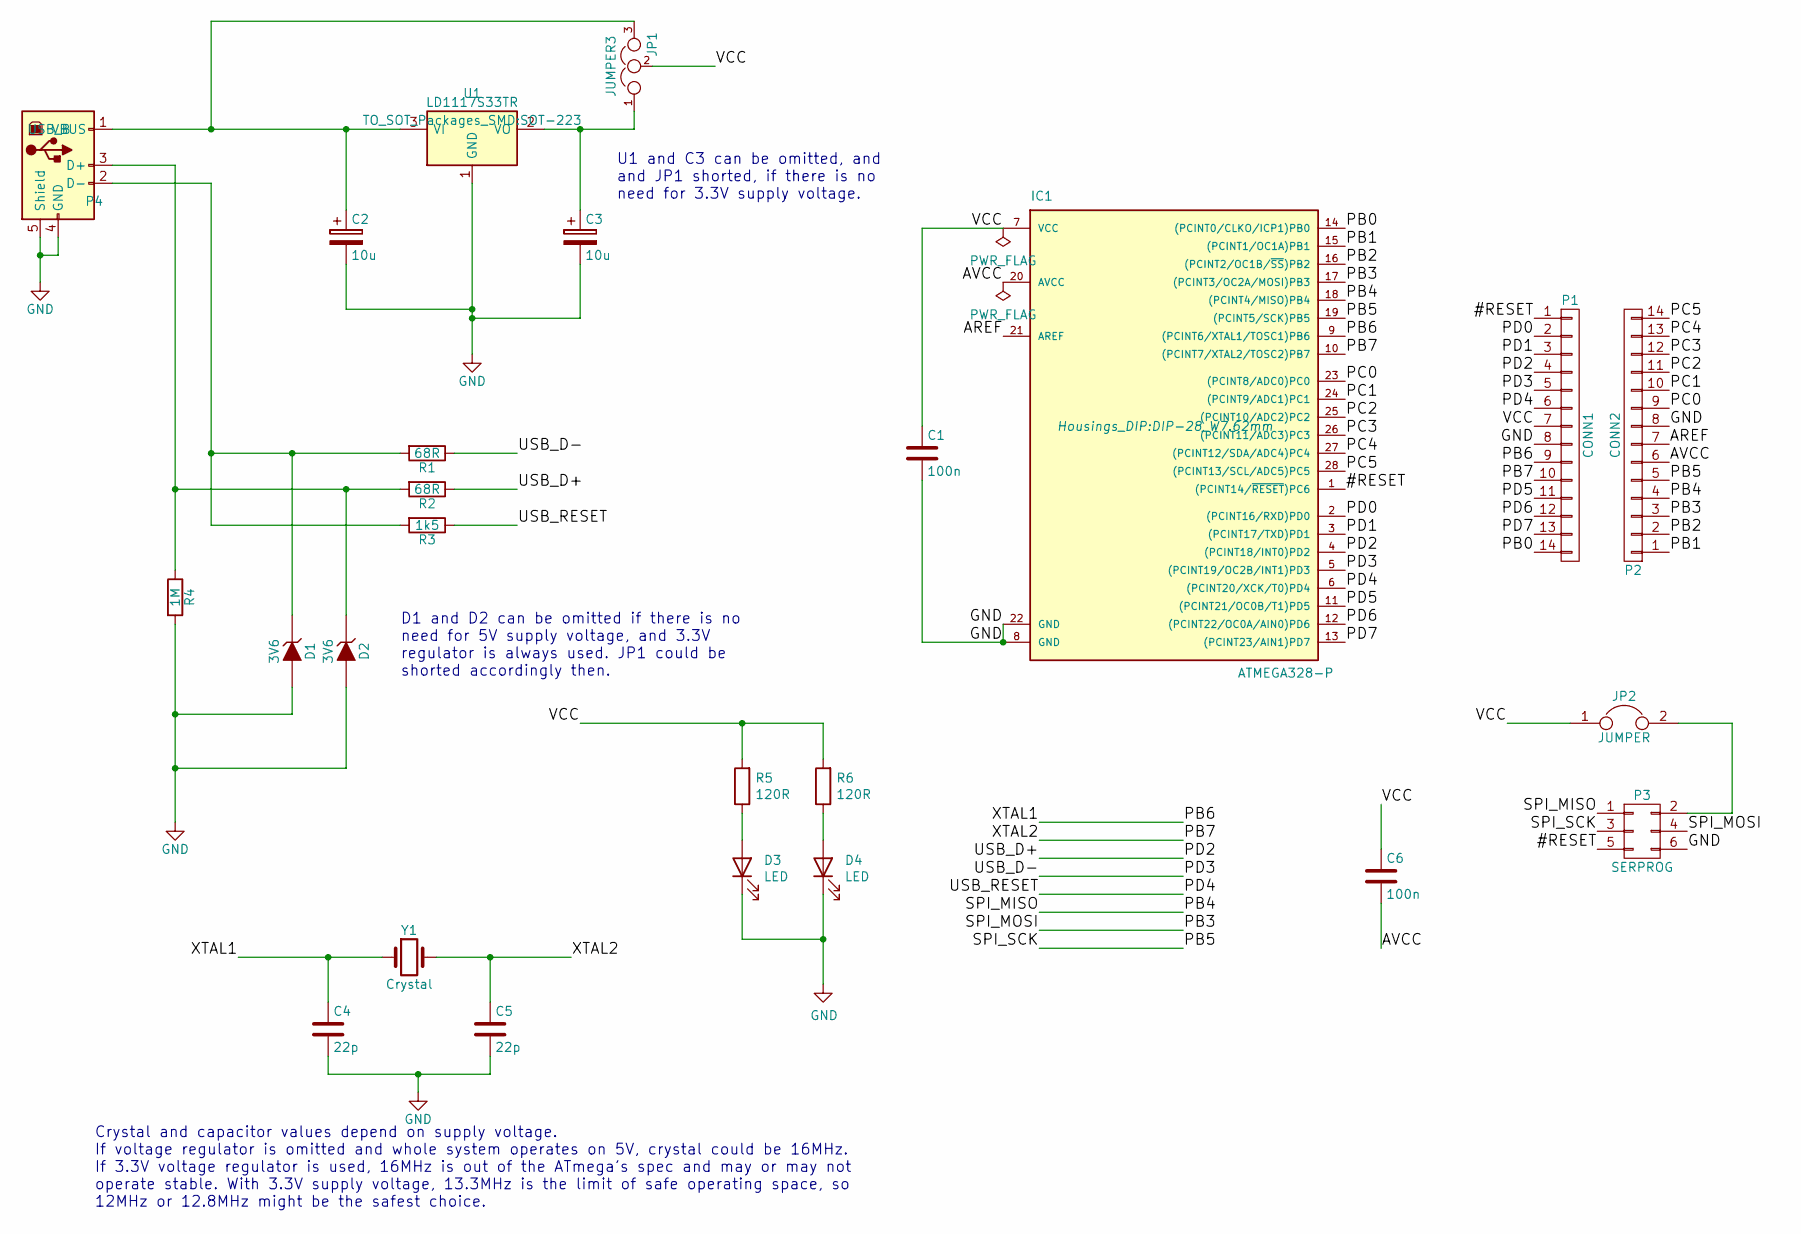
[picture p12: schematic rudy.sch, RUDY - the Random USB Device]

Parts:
C1, C6: 100n; C_0805_2012Metric
C2, C3: 10u; CP_Tantalum_Case-A_EIA-3216-18_Reflow
C4, C5: 22p; C_0805_2012Metric
D1, D2: 3V6; D_SOD-323F
D3, D4: LED; LED_0805_2012Metric
IC1: ATMEGA328-P; DIP-28_W7.62mm
JP1: JUMPER3; Pin_Header_Straight_1x03_Pitch2.54mm
JP2: JUMPER; Pin_Header_Straight_1x02_Pitch2.54mm
P1: CONN1; Socket_Strip_Straight_1x14_Pitch2.54mm
P2: CONN2; Socket_Strip_Straight_1x14_Pitch2.54mm
P3: SERPROG; IDC_Header_Straight_6pins
P4: USB_B; USB_Mini-B
R1, R2: 68R; R_0805_2012Metric
R3: 1k5; R_0805_2012Metric
R4: 1M; R_0805_2012Metric
R5, R6: 120R; R_0805_2012Metric
U1: LD1117S33TR; SOT-223
Y1: Crystal; Crystal_HC49-U_Vertical

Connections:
/#RESET: IC1.1 ((PCINT14/~RESET~)PC6), P1.1, P3.5
/AREF: IC1.21 (AREF), P2.7
/AVCC: C6.2, IC1.20 (AVCC), P2.6
/PB0: IC1.14 ((PCINT0/CLKO/ICP1)PB0), P1.14
/PB1: IC1.15 ((PCINT1/OC1A)PB1), P2.1
/PB2: IC1.16 ((PCINT2/OC1B/~SS~)PB2), P2.2
/PB3: IC1.17 ((PCINT3/OC2A/MOSI)PB3), P2.3, P3.4
/PB4: IC1.18 ((PCINT4/MISO)PB4), P2.4, P3.1
/PB5: IC1.19 ((PCINT5/SCK)PB5), P2.5, P3.3
/PB6: C4.1, IC1.9 ((PCINT6/XTAL1/TOSC1)PB6), P1.9, Y1.1
/PB7: C5.1, IC1.10 ((PCINT7/XTAL2/TOSC2)PB7), P1.10, Y1.2
/PC0: IC1.23 ((PCINT8/ADC0)PC0), P2.9
/PC1: IC1.24 ((PCINT9/ADC1)PC1), P2.10
/PC2: IC1.25 ((PCINT10/ADC2)PC2), P2.11
/PC3: IC1.26 ((PCINT11/ADC3)PC3), P2.12
/PC4: IC1.27 ((PCINT12/SDA/ADC4)PC4), P2.13
/PC5: IC1.28 ((PCINT13/SCL/ADC5)PC5), P2.14
/PD0: IC1.2 ((PCINT16/RXD)PD0), P1.2
/PD1: IC1.3 ((PCINT17/TXD)PD1), P1.3
/PD2: IC1.4 ((PCINT18/INT0)PD2), P1.4, R2.1
/PD3: IC1.5 ((PCINT19/OC2B/INT1)PD3), P1.5, R1.1
/PD4: IC1.6 ((PCINT20/XCK/T0)PD4), P1.6, R3.1
/PD5: IC1.11 ((PCINT21/OC0B/T1)PD5), P1.11
/PD6: IC1.12 ((PCINT22/OC0A/AIN0)PD6), P1.12
/PD7: IC1.13 ((PCINT23/AIN1)PD7), P1.13
/VCC: C1.1, C6.1, IC1.7 (VCC), JP1.2, JP2.1, P1.7, R5.2, R6.2
GND: C1.2, C2.2, C3.2, C4.2, C5.2, D1.2 (A), D2.2 (A), D3.1 (K), D4.1 (K), IC1.8 (GND), IC1.22 (GND), P1.8, P2.8, P3.6, P4.4 (GND), P4.5 (Shield), R4.2, U1.1 (GND)
unnamed: C2.1, JP1.3, P4.1 (VBUS), U1.3 (VI)
unnamed: C3.1, JP1.1, U1.2 (VO)
unnamed: D1.1 (K), P4.2 (D-), R1.2, R3.2
unnamed: D2.1 (K), P4.3 (D+), R2.2, R4.1
unnamed: D3.2 (A), R5.1
unnamed: D4.2 (A), R6.1
unnamed: JP2.2, P3.2

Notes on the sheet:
Crystal and capacitor values depend on supply voltage. If voltage regulator is omitted and whole system operates on 5V, crystal could be 16MHz. If 3.3V voltage regulator is used, 16MHz is out of the ATmega's spec and may or may not operate stable. With 3.3V supply voltage, 13.3MHz is the limit of s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
U1 and C3 can be omitted, and and JP1 shorted, if there is no need for 3.3V supply voltage.
D1 and D2 can be omitted if there is no need for 5V supply voltage, and 3.3V regulator is always used. JP1 could be shorted accordingly then.

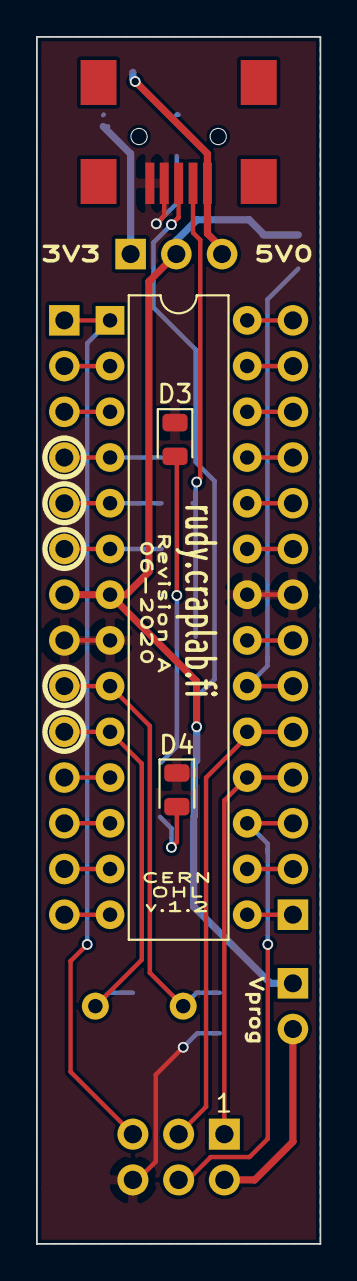
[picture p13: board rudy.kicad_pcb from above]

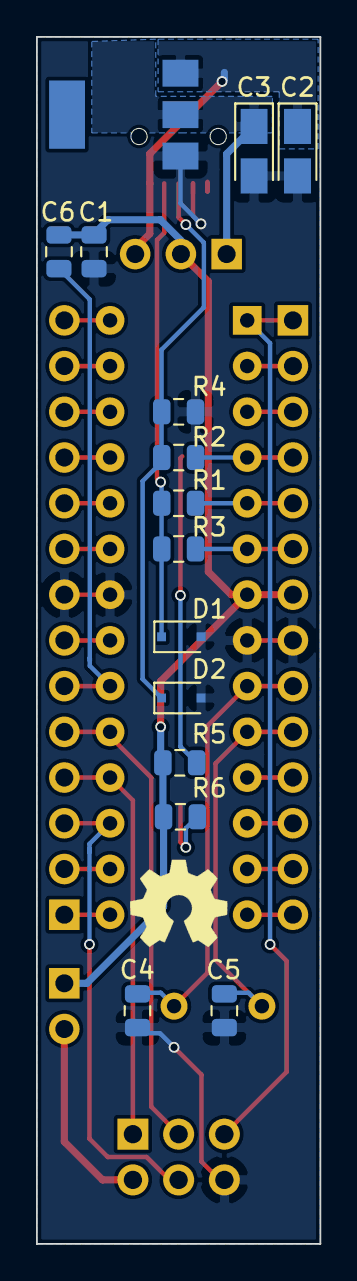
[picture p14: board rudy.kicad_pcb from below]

Board: 2 copper layers, 15.7 x 67.1 mm, 26 parts (16 on the bottom side), 34 nets.

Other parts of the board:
oshw: LOGO; oshw_50

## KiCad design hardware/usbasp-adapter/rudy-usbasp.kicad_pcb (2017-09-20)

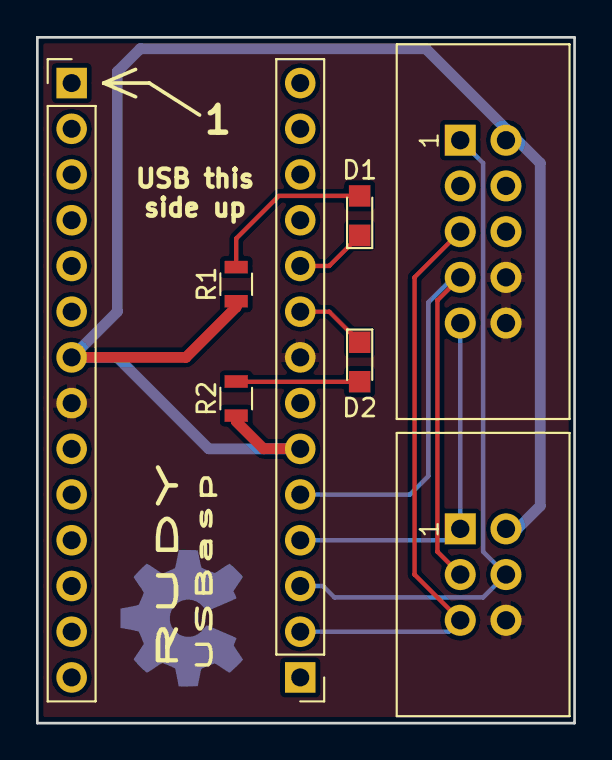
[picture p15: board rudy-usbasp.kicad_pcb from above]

Board: 2 copper layers, 29.8 x 38.1 mm, 8 parts (0 on the bottom side), 10 nets.

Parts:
D1, D2: LED; LED_0805
J1, J2: CONN_01X14; Pin_Header_Straight_1x14_Pitch2.54mm
J3: ISP 6pin; IDC_Header_Straight_6pins
J4: ISP 10pin; IDC_Header_Straight_10pins
R1, R2: 120; R_0805

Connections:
/MISO: J2.4, J3.1, J4.9
/MOSI: J2.3, J3.4, J4.1
/RESET: J2.2, J3.5, J4.5
/SCK: J2.5, J3.3, J4.7
GND: J1.8, J2.8, J3.6, J4.8, J4.10
unnamed: D1.1, J2.10
unnamed: D1.2, R1.2
unnamed: D2.1, J2.9
unnamed: D2.2, R2.2
VCC: J1.7, J2.6, J3.2, J4.2, R1.1, R2.1

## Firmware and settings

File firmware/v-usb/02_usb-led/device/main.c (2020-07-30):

/*
 * RUDY - the Random USB Device
 * USB LED V-USB example - Device side firmware
 *
 * Copyright (C) 2020 Sven Gregori <sven@craplab.fi>
 *
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
 *
 * Example 02: USB LED
 *      Custom device class to control an LED via host-side application.
 *
 *                                         __  __
 *                                       -|1 \/  |-
 *                                       -|      |-
 *                                       -|      |-
 *                                       -|      |-
 *                                       -|      |-
 *                                       -|      |-
 *                                       -|      |-
 *      .----------------------------GND--|8     |-
 *      |                                -|      |-
 *      |      | /|      _______         -|      |-
 *      '------|( |-----|   R   |----PD5--|11    |-
 *             | \|     '-------'        -|      |-
 *                                       -|      |-
 *                                       -|      |-
 *                                        '------'
 *
 * Connect resistor and LED from PD5 (pin 11) to GND (pin 8)
 *
 * Value for R depends on the supply voltage (3.3V or 5.0V) and the LED itself.
 * If in doubt, somewhere around 120 Ohm should probably do for a first test.
 *
 */
#include <avr/io.h>
#include <avr/interrupt.h>
#include <util/delay.h>
#include "usbconfig.h"
#include "usbdrv/usbdrv.h"

/* LED commands, need to be in sync with the host side */
#define CMD_LED_ON  0x01
#define CMD_LED_OFF 0x02
#define CMD_LED_PWM 0x03
#define CMD_GET_PWM 0x04

/* LED port / pin definition, expects LED at PD5 */
#define LED_DDR  DDRD
#define LED_PORT PORTD
#define LED_PIN  PORTD5


/** Flag to track whether PWM is currently ongoing or not */
static uint8_t pwm_active;

/**
 * Buffer to store the currently set PWM value as hex string.
 * Buffer size is 2 bytes to store a single byte value as a string.
 */
static uint8_t pwm_value[2];


/**
 * Set the PWM value buffer to the given value.
 *
 * The value is taken as integer and written as string to the pwm_value
 * buffer. Since the value is a single byte, the buffer is two bytes to
 * represent it as hex value. Note that the buffer isn't zero-terminated
 * as the usbFunctionSetup() function will only send 2 bytes anyway.
 *
 * @param value Integer value to store
 */
static void set_pwm_value_string(uint8_t value)
{
    static uint8_t hex[] = "0123456789abcdef";
    pwm_value[0] = hex[(value >> 4) & 0x0f];
    pwm_value[1] = hex[value & 0x0f];
}


/**
 * Setup 8bit timer to Fast PWM mode with the given value.
 *
 * The given value sets the timer0 output compare register,
 * so the LED will be
 *  - on  for the counting duration of 0 .. value
 *  - off for the counting duration of value .. 255
 * or in other words, the higher value, the brighter the LED.
 *
 * @param val Output compare value
 */
void
timer0_init_pwm(uint8_t value)
{
    if (!pwm_active) {
        /*  PWM phase correct (mode 5) */
        TCCR0A = (1 << COM0B1) | (1 << WGM02) | (1 << WGM00);
        /* Prescaler 256 */
        TCCR0B = (1 << CS02);
    }
    /* Set output compare register to new value */
    OCR0B = value;

    /* Set PWM state tracking flag */
    pwm_active = 1;

    /* Store new PWM value in the buffer */
    set_pwm_value_string(value);
}

/**
 * Stop timer0 and implicity turn LED off (if PWM is ongoing).
 */
void
timer0_stop(void)
{
    if (pwm_active) {
        /* Zero output compare value */
        OCR0B = 0;
        /* Normal timer mode, and set PD5 to regular GPIO */
        TCCR0A = 0;
        /* Prescaler 0, i.e clock off */
        TCCR0B = 0;

        /* Clear PWM state tracking flag */
        pwm_active = 0;

        /* Zero PWM value string */
        set_pwm_value_string(0x00);
    }
}


/**
 * V-USB setup callback function.
 *
 * Called from within V-USB when the host requests as setup transaction.
 * As this here acts as a non-standard, vendor-specific USB device class,
 * this is sent for every device control transfer, which is essentially
 * the way the host-side control application actually communicates with
 * the device itself here.
 *
 * For more information, check its documentation in usbdrv.h 
 *
 * @param data Setup data
 */
uchar
usbFunctionSetup(uchar data[8])
{
    /*
     * Cast given raw data to usbRequest_t structure.
     *
     * The struct itself is the main data structure for any communcation
     * between the host and device for a custom class device like this.
     * On the host side, libusb's control transfer messages uses the exact
     * same content that ends up in the usbRequest_t here / is sent back.
     *
     * The struct is defined in common/usbdrv/usbdrv.h and further explained
     * in the V-USB wiki: http://vusb.wikidot.com/driver-api
     *
     * Let's have a quick look to make more sense out of this function here:
     * 
     *  typedef struct usbRequest{
     *      uchar       bmRequestType;
     *      uchar       bRequest;
     *      usbWord_t   wValue;
     *      usbWord_t   wIndex;
     *      usbWord_t   wLength;
     *  }usbRequest_t;
     *
     * bmRequestType - The nature of the request itself, e.g. who communicates
     *                 with whom (host->device or device->host).
     *                 Content is a bit-mask (bitfield), hence the "bm" prefix
     *
     * bRequest      - The request itself, in this case it's whatever we want
     *                 it to be, e.g. CMD_LED_ON.
     *                 Content is a byte value, hence the "b" prefix
     *
     * wValue        - For custom class devices, this doesn't have any fixed
     *                 meaning, and we can abuse it for any sending arbitrary
     *                 data between host and device, e.g. the PWM value in
     *                 the CMD_LED_PWM and CMD_GET_PWM bRequests.
     *                 Content is a 16-bit word value, hence the "w" prefix
     *
     * wIndex        - Same as wValue in case of custom class devices, but
     *                 unused in this example code. It could provide another
     *                 aribtrary 16-bit value if needed.
     *                 Content is a 16-bit word value, hence the "w" prefix
     *
     * wLength       - Length in bytes of additional data if there is a data
     *                 transfer included. When sending data to the device
     *                 and those 32 bit we can utilize via the wValue and
     *                 wIndex parameters aren't enough, or when sending data
     *                 back to the host, that data is transferred separately
     *                 and both sides need to know the size of that data.
     *                 This LED example makes briefly use of that in the
     *                 CMD_GET_PWM request - check below for details. Other
     *                 ways to make use of that are implemented and shown
     *                 in the 03_caesar example code.
     *                 Content is a 16-bit word value, hence the "w" prefix
     */
    usbRequest_t *rq = (void *) data;

    /* Check and handle request type */
    switch (rq->bRequest) {
        case CMD_LED_ON:
            /*
             * Turn LED on.
             *
             * From USB side, there's not much to this, the request has no
             * additional data. Simply toggle the output pin, and stop the
             * PWM timer if necessary.
             */
            timer0_stop();
            LED_PORT |= (1 << LED_PIN);
            break;

        case CMD_LED_OFF:
            /*
             * Turn LED off.
             *
             * Same as the CMD_LED_ON request, nothing further to handle
             * from USB point of view, so just toggle the pin and also stop
             * the PWM timer if necessary.
             */
            timer0_stop();
            LED_PORT &= ~(1 << LED_PIN);
            break;

        case CMD_LED_PWM:
            /*
             * Set LED to given PWM value.
             *
             * PWM value itself is sent in the rq->wValue field.
             * As stated above, the wValue parameter is a 16-bit wide word
             * value, but we only use an 8-bit timer here, so therefore only
             * the lower 8 bits will be used, and everything else is ignored.
             * 
             * Note that we could also use rq->wValue.bytes[0] instead of
             * AND'ing rq->wValue.word with 0xff, but personally, the latter
             * one feels more explicit and obvious than the former, as it
             * doesn't require to consider byte order.
             */
            timer0_init_pwm((rq->wValue.word & 0xff));
            break;

        case CMD_GET_PWM:
            /*
             * Return the current pwm_value string.
             *
             * The request itself will have the wLength value set by the host
             * to tell how big of a buffer it has allocated to receive the
             * data here / how much bytes it will care to receive. If we send
             * less than expected, the host simply receives less without any
             * consequences; if we send more than expected, V-USB itself will
             * limit the size to make sure there won't be any consequences for
             * the host either. The latter will however silently discard data
             * we intended to send, so it's a good idea to check if the sizes
             * will match.
             *
             * To send data back to the host, we have two options:
             *  1) point V-USB's internal usbMsgPtr variable to the location
             *     in RAM (i.e. a regular, non-PROGMEM variable) we want to
             *     send there, and return the size of it in this function
             *
             *  2) use the usbFunctionRead callback (yes, Read, communication
             *     is considered from the host's point of view, and as we
             *     send data back to it, the host is the one reading here)
             *
             * In this example, we use the simpler first option and just point
             * usbMsgPtr to our pwm_value buffer. For more details on the more
             * complex (and thus more powerful / flexibly) second option, have
             * a look at the 03_caesar example.
             */
            if (rq->wLength.word < sizeof(pwm_value)) {
                /*
                 * Length is indeed smaller than our value buffer.
                 * Unfortunately we cannot directly indicate an error here,
                 * so instead, we return 0 here so nothing is actually send
                 * back to the host at all.
                 *
                 * To turn this into proper error handling, the host-side
                 * control application needs to check if the received data
                 * is of length zero or not (../host/ledcontrol.py does so)
                 */
                return 0;
            }

            /* Point usbMsgPtr to our pwm_value buffer and return its size */
            usbMsgPtr = pwm_value;
            return sizeof(pwm_value);
    }

    /* In any other case, including unknown requests, simply return 0 */
    return 0;
}


/*
 * And off we go..
 */
int
main(void)
{
    /* Set up GPIO, set LED pin as output and turn it off */
    LED_DDR = (1 << LED_PIN);
    LED_PORT = 0x00;

    /*
     * By default, shine the LED via PWM at ~25% duty cycle.
     *
     * This achieves three things:
     *  1) instant feedback that everything is set up properly and works
     *  2) lower the risk to kill the LED if current-limiting resistor is
     *     either too low or was omitted altogether
     *  3) indicate in case a way too high current-limiting resistor was
     *     used, as this should ideally have a nice, bright-enough glow.
     */
    timer0_init_pwm(0x3f);

    /* Disconnect and reconnect USB to enforce device re-enumeration */
    usbDeviceDisconnect();
    _delay_ms(200);
    usbDeviceConnect();

    /** Init USB and enable interrupts */
    usbInit();
    sei();

    /* Loop forever */
    while (1) {
        /*
         * usbPoll() needs to be called periodically (at least every 50ms),
         * or else the USB connection times out and is dropped. But nothing
         * else is going on in here, so we can easily delay a little while.
         */
        usbPoll();
        _delay_ms(30);
    }

    return 0;
}

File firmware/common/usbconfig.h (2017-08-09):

/* Name: usbconfig.h
 * Project: V-USB, virtual USB port for Atmel's(r) AVR(r) microcontrollers
 * Author: Christian Starkjohann
 * Creation Date: 2005-04-01
 * Tabsize: 4
 * Copyright: (c) 2005 by OBJECTIVE DEVELOPMENT Software GmbH
 * License: GNU GPL v2 (see License.txt), GNU GPL v3 or proprietary (CommercialLicense.txt)
 */

/*
 * Based on vusb-20121206/usbdrv/usbconfig-prototype.h
 * Adjusted for RUDY - the Random USB Device
 * This file defines all common and default values.
 * Each example can override these settings with the following steps:
 *      1. add "CLAGS += -DHAS_CONFIG_OVERRIDES" in its Makefile
 *      2. create usbconfig_overrides.h file for the exaple
 *      3. #undef <CONFIG_DEFINE>
 *      4. #define <CONFIG_DEFINE> <NEW_VALUE>
 */

#ifndef __usbconfig_h_included__
#define __usbconfig_h_included__

/* ---------------------------- Hardware Config ---------------------------- */

#define USB_CFG_IOPORTNAME      D
/* This is the port where the USB bus is connected. When you configure it to
 * "B", the registers PORTB, PINB and DDRB will be used.
 */
#define USB_CFG_DMINUS_BIT      3
/* This is the bit number in USB_CFG_IOPORT where the USB D- line is connected.
 * This may be any bit in the port.
 */
#define USB_CFG_DPLUS_BIT       2
/* This is the bit number in USB_CFG_IOPORT where the USB D+ line is connected.
 * This may be any bit in the port. Please note that D+ must also be connected
 * to interrupt pin INT0! [You can also use other interrupts, see section
 * "Optional MCU Description" below, or you can connect D- to the interrupt, as
 * it is required if you use the USB_COUNT_SOF feature. If you use D- for the
 * interrupt, the USB interrupt will also be triggered at Start-Of-Frame
 * markers every millisecond.]
 */
#define USB_CFG_CLOCK_KHZ       (F_CPU/1000)
/* Clock rate of the AVR in kHz. Legal values are 12000, 12800, 15000, 16000,
 * 16500, 18000 and 20000. The 12.8 MHz and 16.5 MHz versions of the code
 * require no crystal, they tolerate +/- 1% deviation from the nominal
 * frequency. All other rates require a precision of 2000 ppm and thus a
 * crystal!
 * Since F_CPU should be defined to your actual clock rate anyway, you should
 * not need to modify this setting.
 */
#define USB_CFG_CHECK_CRC       0
/* Define this to 1 if you want that the driver checks integrity of incoming
 * data packets (CRC checks). CRC checks cost quite a bit of code size and are
 * currently only available for 18 MHz crystal clock. You must choose
 * USB_CFG_CLOCK_KHZ = 18000 if you enable this option.
 */

/* ----------------------- Optional Hardware Config ------------------------ */

#define USB_CFG_PULLUP_IOPORTNAME   D
/* If you connect the 1.5k pullup resistor from D- to a port pin instead of
 * V+, you can connect and disconnect the device from firmware by calling
 * the macros usbDeviceConnect() and usbDeviceDisconnect() (see usbdrv.h).
 * This constant defines the port on which the pullup resistor is connected.
 */
#define USB_CFG_PULLUP_BIT          4
/* This constant defines the bit number in USB_CFG_PULLUP_IOPORT (defined
 * above) where the 1.5k pullup resistor is connected. See description
 * above for details.
 */

/* --------------------------- Functional Range ---------------------------- */
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

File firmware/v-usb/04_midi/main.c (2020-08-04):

/*
 * RUDY - the Random USB Device
 * USB MIDI V-USB example
 *
 * Copyright (C) 2020 Sven Gregori <sven@craplab.fi>
 *
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
 */
 /*
 * Example 03: MIDI device
 *
 *      This is a combination of USB MIDI and Analog to Digital Conversion.
 *      An arbitrary sensor can be hooked up to an ADC channel, and the device
 *      will periodically send MIDI notes depending on the sensor values read
 *      by the ADC. Take for example a photoresistor (LDR, light sensor), and
 *      the brighter the light, the higher (or lower) the note.
 *
 *      The USB MIDI setup part is taken directly from the 4chord MIDI project,
 *      see https://github.com/sgreg/4chord-midi for more information on that.
 *
 *      Note that while the ADC part should work well enough, it's not the most
 *      ideal setup for a real world sensor reading setup. For more information
 *      on how to improve Analog to Digital conversions, check out Microchip's
 *      application note AN2538 (formerly known as AVR126 when it was still
 *      Atmel) titled "ADC of megaAVR in Single-Ended Mode".
 *
 *
 * Example hardware setup:
 *
 *       .-----------------------------.
 *       |                             |
 *       |           __  __          .---.
 *       |         -|1 \/  |-        |   |  Variable resistor as sensor
 *       |         -|      |-        | R |  e.g. LDR, force sensor, NTC
 *       |         -|      |-        | 1 |  (or simply a potentiometer)
 *       |         -|      |-        |___|
 *       |         -|      |-          |
 *       |         -|    23|--ADC0-----+
 *       '-----VCC--|7     |-          |
 *       .-----GND--|8     |-        .---.
 *       |         -|      |-        |   |  Matching resistor to complete
 *       |         -|      |-        | R    the voltage divider to get a
 *       |         -|      |-        | 2 |  good sensor value range
 *       |         -|      |-        |___|
 *       |         -|      |-          |
 *       |         -|      |-          |
 *       |          '------'           |
 *       |                             |
 *       '-----------------------------'
 *
 *
 * An alternative option is to use a standalone sensor that directly outputs
 * their analog voltage value instead of having variable resistance that
 * requires the voltage divider setup - for example the ADXL335 accelerometer
 * or an LM35 temperature sensor.
 *
 */
#include <string.h>
#include <avr/io.h>
#include <avr/interrupt.h>
#include <util/delay.h>
#include <usbdrv/usbdrv.h>
#include "usbconfig.h"


/** ADC Channel (and ADCx pin) the sensor is connected to */
#define ADC_CHANNEL 0

/** Number of samples multiplier, will result in 2^ADC_SAMPLES_MUL samples */
#define ADC_SAMPLES_MUL 2
/** Number of samples to take the average ADC value from */
#define ADC_SAMPLES (1 << ADC_SAMPLES_MUL)


/*
 * USB MIDI device and configuration descriptor setup
 * For more details, refer to the Universal Serial Bus Device Class Definition
 * for MIDI Devices Release 1.0 document found at
 * https://usb.org/sites/default/files/midi10.pdf
 *
 * The descriptor definition is based and taken from the example found in
 * the above mentioned document, Appendix B.1. and was adjusted to provide
 * one interface (MIDI IN Jack) with one bulk endpoint.
 */

/*
 * USB MIDI adapter device descriptor.
 * Based on the USB device class definition example found in Appendix B.1
 */
const uint8_t usb_midi_device_descriptor[] PROGMEM = {
    0x12,                   /* [1] size of this descriptor in bytes (18)    */
    USBDESCR_DEVICE,        /* [1] descriptor type (DEVICE)                 */
    0x10, 0x01,             /* [2] supported USB version (1.10)             */
    0x00,                   /* [1] device class, defined at interface level */
    0x00,                   /* [1] subclass, unused                         */
    0x00,                   /* [1] protocol, unused                         */
    0x08,                   /* [1] max packet size in bytes (8)             */
    USB_CFG_VENDOR_ID,      /* [2] vendor ID (see usbconfig.h)              */
    USB_CFG_DEVICE_ID,      /* [2] device ID (see usbconfig.)               */
    USB_CFG_DEVICE_VERSION, /* [2] device release version (see usbconfig.h) */
    0x01,                   /* [1] manufacturer string index (1)            */
    0x02,                   /* [1] product string index (2)                 */
    0x00,                   /* [1] serial number string index, unused       */
    0x01,                   /* [1] number of configurations (1)             */
};

/*
 * USB MIDI configuration adapter descriptor.
 * Based on the USB device class definition example found in Appendix B.2-B.6
 */
const uint8_t usb_midi_config_descriptor[] PROGMEM = {
/* B.2   Configuration Descriptor */
    0x09,               /* [1] size of this descriptor in bytes (9)         */
    USBDESCR_CONFIG,    /* [1] descriptor type (CONFIGURATION)              */
    0x3f, 0x00,         /* [2] total length of descriptor in bytes (63)     */
    0x02,               /* [1] number of interfaces (2)                     */
    0x01,               /* [1] ID of this configuration (1)                 */
    0x00,               /* [1] configuration, unused                        */
    USBATTR_BUSPOWER,   /* [1] attributes                                   */
    0x32,               /* [1] max USB power in 2mA units (50 == 100mA)     */

/* B.3   AudioControl Interface Descriptor */
/* B.3.1 Standard AudioControl Interface Descriptor                         */
    0x09,               /* [1] size of this descriptor in bytes (9)         */
    USBDESCR_INTERFACE, /* [1] descriptor type (INTERFACE)                  */
    0x00,               /* [1] index of this interface (0)                  */
    0x00,               /* [1] index of this setting (0)                    */
    0x00,               /* [1] number of endpoints to follow (0)            */
    0x01,               /* [1] interface class (AUDIO)                      */
    0x01,               /* [1] interface sublass (AUDIO_CONTROL)            */
    0x00,               /* [1] interface protocol, unused                   */
    0x00,               /* [1] interface, unused                            */

/* B.3.2 Class-specific AudioControl Interface Descriptor */
    0x09,               /* [1] size of this descriptor in bytes (9)         */
    0x24,               /* [1] descriptor type (CS_INTERFACE)               */
    0x01,               /* [1] header subtype                               */
    0x00, 0x01,         /* [2] revision of class specification (1.0)        */
    0x09, 0x00,         /* [2] total size of class spec descriptor (9)      */
    0x01,               /* [1] number of streaming interfaces (1)           */
    0x01,               /* [1] MIDIStreaming iface 1 belongs to this iface  */
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

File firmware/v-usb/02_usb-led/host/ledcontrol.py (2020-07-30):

#!/usr/bin/env python3
#
# RUDY - the Random USB Device
# USB LED V-USB example - host side Python script
#
# Copyright (C) 2020 Sven Gregori <sven@craplab.fi>
#
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
import sys
import usb.core

# Expected USB device information
USB_VID = 0x1209
USB_PID = 0xb00b
USB_SERIAL_NUMBER = "LED Example"

# USB request types
USB_SEND = 0x40
USB_RECV = 0xC0

# LED control commands (make sure these are kept in sync with the device side firmware)
CMD_LED_ON  = 0x01
CMD_LED_OFF = 0x02
CMD_LED_PWM = 0x03
CMD_GET_PWM = 0x04


# Try to find a device that matches the expected vendor ID and product ID
dev = usb.core.find(idVendor=USB_VID, idProduct=USB_PID)

# Check that a matching device is connected
if dev is None:
    print('Error: No device found')
    sys.exit(1)

# Make sure it's the expected device based on its serial number data
if dev.serial_number != USB_SERIAL_NUMBER:
    print('Error: expected serial number "{}" but got "{}"'.format(USB_SERIAL_NUMBER, dev.serial_number))
    sys.exit(1)

# Matching device found, we're ready to go - start with some help ouptut
print("""Welcome to {}

Available commands:
on              turn LED on
off             turn LED off
pwm             read the current PWM value
pwm <value>     set LED to given PWM value
                value can be either decimal [0..255] or hexadecimal [0x00..0xff]
q | quit        quit

""".format(dev.serial_number))

run = True
while run:
    try:
        cmd = input("> ")

        if cmd == "q" or cmd == "quit":
            run = False

        elif cmd == "on":
            # "on" command, write SEND reqest with CMD_LED_ON and no additional data
            #
            # The third and fourth parameter (wValue and wIndex) are zero here and could be
            # therefore omitted. In other cases we could send two 16bit values to the device
            # here, so for completeness, the parameters are included here.
            dev.ctrl_transfer(USB_SEND, CMD_LED_ON, 0, 0)

        elif cmd == "off":
            # "off" command, write SEND reqest with CMD_LED_OFF and no additional data
            #
            # This time, the third and fourth parmater (wValue and wIndex) are omitted,
            # just to demonstrate both options. 
            dev.ctrl_transfer(USB_SEND, CMD_LED_OFF)

        elif cmd == "pwm":
            # "pwm" command, read PWM value with CMD_GET_PWM
            #
            # Since a value is read back from the device here, things are slighty different:
            #   - the request type needs to be USB_RECV instead of USB_SEND
            #   - a fifth parameter is needed to define how many bytes to read
            #   - the returned data is an array object containg raw bytes
            #
            # The returned data needs to be converted to a string to make use of it,
            # and in this case, it's the hexadecimal value (without 0x prefix) of the
            # current PWM value, therefore we need to read 2 bytes (as the PWM value
            # itself is one byte, which requires two characters to represent as string)
            #

            # Read 2 bytes via CMD_GET_PWM command
            pwm_value = dev.ctrl_transfer(USB_RECV, CMD_GET_PWM, 0, 0, 2)
            # Alternatively, we could call:
            #   pwm_value = dev.ctrl_transfer(USB_RECV, CMD_GET_PWM, data_or_wLength=2)
            # and again omit the unused wValue and wIndex parameters
            #
            # Note that the size parameter (2 bytes here) is the *maximum* number of bytes
            # that is attempted to be received here. If less data is sent by the device,
            # simply less data is received; if more data is sent, the rest of it is ignored.

            # Convert received data to string
            pwm_value_string = pwm_value.tostring().decode('ASCII')

            # Convert string to integer value - if possible.
            # If conversion fails, chances are nothing was received from the device side.
            # Reason for that could a too small receive buffer size (see ../device/main.c)
            try:
                int_value = int(pwm_value_string, 16);
                # Display the current PWM value both in hexadecimal and decimal
                print("Current PWM value: 0x{} ({})".format(pwm_value_string, int_value))
            except ValueError:
                print('Failed to retrieve PWM value, received "{}"'.format(pwm_value_string))


        elif cmd[:4] == "pwm " and len(cmd) > 4:
            # "pwm <value>" command, write SEND request with CMD_LED_PWM and a given value
            #
            # The given value itself can be either decimal or hexadecimal, and is sent using
            # the third wValue paramter. Note that the "w" prefix denotes that the variable
            # is of "word sized value", which in this case means 16-bit. However, the device
            # uses an 8-bit timer, so only the lower byte of the value is actually used, and
            # the device-side code will simply ignore the higher byte.
            #
            # e.g. a value of 666 (0x029a) will simply result in a value of 154 (0x009a)
            # 

            # First, parse the given value string to an integer.
            #
            # Extract the value from the cmd string, and check if it starts with "0x",
            # in which case the value string is treated as a hexadecimal value.
            # Otherwise, it's treated as a regular decimal value.
            value = cmd[4:].lower()
            base = 10
            if value[:2] == "0x":
                base = 16
            try:
                dev.ctrl_transfer(USB_SEND, CMD_LED_PWM, int(value, base), 0)
            except ValueError:
                print("Cannot convert '{}' to integer".format(value))

        else:
            print("Unknown command '{}'".format(cmd))

    except (KeyboardInterrupt, EOFError):
        print("")
        run = False

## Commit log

2017-07-23 Hardware Revision A
    Added full KiCad project with schematic (plus PDF), PCB design, net list
    and BOM, plus KiCad project itself, of Revision A hardware.
    [rudy.kicad_pcb, rudy.sch]
2017-07-23 Added Gerber files for hardware Revision A
    [rudy-B.Cu.gbr, rudy-B.Mask.gbr, rudy-B.SilkS.gbr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]
2017-07-24 Added common firmware files and Hello USB example
    All initial common files, including the V-USB library itself and a
    generic Makefile, along with a simple Hello USB dummy device.
2017-08-09 Hardware revision A adjustments
    Second iteration, changing SMD footprints from hand solder types to
    normal / reflow types. Re-arranging power selector and re-routing
    everything, fixing some minor general things along the way.
    Changed Zener diode / resistor order for USB D+/D- lines.
    Added solder paste layer Gerber file.
    [rudy-B.Cu.gbr, rudy-B.Mask.gbr, rudy-B.Paste.gbr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]
2017-08-09 Changed USB port config to match actual hardware
    Previous port assignments were based on 4chord MIDI hardware. Now real
    RUDY hardware has arrived, which uses different pins, need to adjust it.
    Also added RUDY's own dedicated USB VID/PID pair, courtesy of pid.codes
    and InterBiometrics.
2017-08-09 Update for latest KiCAD version
    Never updated the KiCAD ppa after last dist upgrade, so been using old
    version ever since, now updated and had to adjust one component.
    Changed Gerber file extension format along the way.
    [rudy-B.Cu.gbl, rudy-B.Mask.gbs, rudy-B.Paste.gbp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]
2017-08-21 Changed Zener diodes
    Changed footprint for D1 and D2 Zener diodes from Mini MILF to SOD-323F
    and moved their position in front of R1 and R2.
    That came with a bit of rerouting, and trying to keep the pad position
    close enough to the initial ones, so I don't have to order new stencils
    right away (while even still waiting for them)
    [rudy-B.Cu.gbl, rudy-B.Mask.gbs, rudy-B.Paste.gbp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]
2017-09-12 Fixed USB-B component after KiCad update
    Turns out 1-3-2-4-5 is a more logical pin arrangement for some people,
    and I fucked up paying attention to this, so D+ and D- USB lines got
    swapped in the schematic component. Should have been more suspicious
    why I had to do so much re-routing after updating the Zener diodes.
    [rudy-B.Cu.gbl, rudy-B.Mask.gbs, rudy-B.Paste.gbp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]
2017-09-20 Updated README to current state and added new items
    First prototypes got soldered and new ideas (USBasp) came up.
2017-09-20 USBasp adapter board hardware added
    Simple adapter board with a 6pin and 10pin IDC connector, LEDs and
    resistors for power / connection indication (handled by USBasp firmware)
    and two female 14pin headers to dock RUDY into.
    When RUDY is programmed with USBasp firmware, it can act as fully
    functional USBasp programmer with this board.
    [rudy-usbasp-B.Cu.gbl, rudy-usbasp-B.Mask.gbs, rudy-usbasp-B.Paste.gbp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]
2017-09-20 Some gitignore adjustments
    Keep cache lib for KiCad schematics and fix some wildcards
2020-07-21 HW: added LEDs and AVCC cap
    There were no LEDs.
    Why were there no LEDs?!
    Everything needs LEDs!
    So now there are, indicating that the device is actually powered, which
    will lessen occasional confusion about that (especially when one forgets
    to adjust the jumper after flashing).
    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
    [rudy-B.Cu.gbl, rudy-B.Mask.gbs, rudy-B.Paste.gbp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]
2020-07-21 FW: moved examples and refactored V-USB config override handling
    V-USB is great, but even though this is specifically a Random *USB*
    Device, it doesn't have to be, and using V-USB functionality is really
    more optional, and is therefore now separated.
    Not that there's much to separate it from, but now it's easier to add
    bare metal examples in the future.
    While moving the examples, the config handling for V-USB was refactored
    along the way. It didn't make sense anymore to explicitly undef the
    values to override them. Instead, the main usbconfig.h uses values set
    in an usbconfig-rudy.h override header file that can be adjusted for
    each example project individually.
    [main.c, usbconfig-rudy.h, usbconfig.h]
2020-07-22 FW: USB interrupt-in endpoints are project-specific now
    `USB_CFG_HAVE_INTRIN_ENDPOINT`/`3` values are not hardcoded anymore but
    defined in the usbconfig-rudy.h by each project now.
2020-07-24 FW: usbconfig settings moved to override file
    More settings moved: `USB_CFG_INTR_POLL_INTERVAL` for setting the
    interrupt polling interval, and `USB_CFG_HID_REPORT_DESCRIPTOR_LENGTH`
    for HID devices.
    Also removed some old leftover parts from the previous override way
2020-07-28 FW: Added general information and instructions about firmware
    README with general info on the firmware files, build instructions,
    flashing instructions, powering up, installing dependencies, etc.
2020-07-28 Updated main README
    RUDY is going forward, time to update the README and add the current
    state and what's going on here.
2020-07-28 FW: Added V-USB Example 02: USB LED
    Control an LED via USB. Allows to turn the an LED connected to port PD5
    to be turned on, off, or set to a specific PWM value via USB.
    Includes a Python script to communicate with the device.
2020-07-28 FW: use correct binutils package for Debian in check-system script
    Like avr-gcc / gcc-avr, it's the same with avr-binutils / binutils-avr,
    which wasn't handled properly. Now it is, and since there's plenty of
    checking /etc/*release now, the script just determines the distro right
    away in the beginning.
    Also, this must be actual bash script, not sh, as it uses bash-specific
    stuff like += operator (fails at Raspberry Pi for example)
2020-07-29 Bunch of README fixes
    Some typo here, some wrong word there. Also missed the part about having
    its own USB VID/PID pair. And there was a section prepared to build the
    firmware via Docker, but decided against that for now - kinda doesn't
    make much sense if AVR toolchains are more or less available out of the
    box in most cases.
2020-07-29 FW: Added V-USB Example 03: Caesar Cipher
    Send messages to the device and receive it back shifted with the Caesar
    Cipher of a given amount of places.
    Includes also a Python script to communicate with the device
2020-07-29 FW: Added V-USB Example 04: MIDI
    Turn RUDY into a USB MIDI device and connect a sensor to its ADC to
    create the MIDI notes in the first place
2020-08-01 FW: Added Arduino information
2020-08-01 FW: Added Arduino Example 01: Blinky
    It's just the usual blinking LED example, but adjusted for RUDY, which
    expects an external LED connected to Digital Pin 5 / pin 11
2020-08-01 FW: Added arduino/ firmware folder to README
